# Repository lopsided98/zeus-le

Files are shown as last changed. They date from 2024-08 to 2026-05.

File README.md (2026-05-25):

# zeus-le

### Synchronized wireless audio recording system

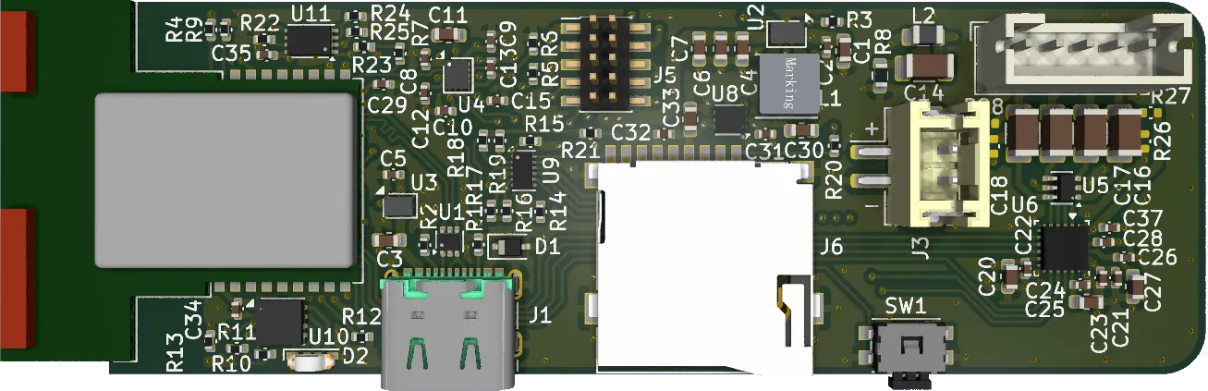
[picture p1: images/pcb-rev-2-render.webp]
Render of zeus-le rev-2 PCB


zeus-le is a system to allow a set of wireless digital audio recorders to maintain sub-sample accurate time synchronization over indefinite periods. A central node broadcasts periodic synchronization packets over Bluetooth LE, which are received by an arbitrary number of recording nodes. The recording nodes use a digital phase-locked loop (PLL) to keep the audio sample clock in sync with the reference. The PLL is implemented using a Kalman filter and linear quadratic regulator.

This repository contains both firmware source code and a custom PCB design for the audio recording hardware. The firmware is written in C for a Nordic nRF53 running Zephyr RTOS. The PCB is designed in KiCad and hosts an nRF53+nRF7002 module, battery charger, SD card, audio ADC and voltage regulators.

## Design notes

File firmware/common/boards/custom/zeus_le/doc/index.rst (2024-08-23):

.. _zeus_le_nrf5340:

zeus-le
###################

Overview
********

zeus-le board is based on the Fanstel WT02C40C module, using the Nordic
Semiconductor nRF5340 ARM Cortex-M33 SoC.

The nRF5340 inside the WT02C40C module is a
dual-core SoC based on the Arm® Cortex®-M33 architecture, with:

* a full-featured Arm Cortex-M33F core with DSP instructions, FPU, and
  Armv8-M Security Extension, running at up to 128 MHz, referred to as
  the **application core**
* a secondary Arm Cortex-M33 core, with a reduced feature set, running
  at a fixed 64 MHz, referred to as the **network core**.

The ``zeus_le/nrf5340/cpuapp`` build target provides support for the application
core on the nRF5340 SoC. The ``zeus_le/nrf5340/cpuapp`` build target provides
support for the network core on the nRF5340 SoC.

nRF5340 SoC provides support for the following devices:

* :abbr:`ADC (Analog to Digital Converter)`
* CLOCK
* FLASH
* :abbr:`GPIO (General Purpose Input Output)`
* :abbr:`IDAU (Implementation Defined Attribution Unit)`
* :abbr:`I2C (Inter-Integrated Circuit)`
* :abbr:`MPU (Memory Protection Unit)`
* :abbr:`NVIC (Nested Vectored Interrupt Controller)`
* :abbr:`PWM (Pulse Width Modulation)`
* :abbr:`QSPI (Quad Serial Peripheral Interface)`
* RADIO (Bluetooth Low Energy and 802.15.4)
* :abbr:`RTC (nRF RTC System Clock)`
* Segger RTT (RTT Console)
* :abbr:`SPI (Serial Peripheral Interface)`
* :abbr:`UARTE (Universal asynchronous receiver-transmitter)`
* :abbr:`WDT (Watchdog Timer)`

zeus-le

     zeus-le

The `pcb` directory contains the board's schematic.

Hardware
********
- Synchronized audio recording board
- Nordic nRF5340 SoC Solution
- A recommnded 3rd-party module by Nordic Semiconductor.
- Dual-core Arm® Cortex® M33
- 1MB/256KB Flash Memory; 512kB/ 64kB RAM
- Supports BT5 Long Range Features
- Bluetooth specification v5.2
- Supports Bluetooth Direction Finding & Mesh
- Supports Bluetooth low energy audio
- Chip Antenna
- Highly flexible multiprotocol SoC ideally suited for Bluetooth® Low Energy, ANT+, Zigbee, Thread (802.15.4) ultra low-power wireless applications.
- RGB LED with animation driver
- Pushbutton
- 1 USB-C connector for battery charging and communication
- BMDU connector for FW programing and UART communication

Supported Features
==================

The ``zeus_le_nrf5340/cpuapp`` board configuration supports the following
hardware features:

+-----------+------------+----------------------+
| Interface | Controller | Driver/Component     |
+===========+============+======================+
| ADC       | on-chip    | adc                  |
+-----------+------------+----------------------+
| CLOCK     | on-chip    | clock_control        |
+-----------+------------+----------------------+
| FLASH     | on-chip    | flash                |
+-----------+------------+----------------------+
| GPIO      | on-chip    | gpio                 |
+-----------+------------+----------------------+
| I2C(M)    | on-chip    | i2c                  |
+-----------+------------+----------------------+
| MPU       | on-chip    | arch/arm             |
+-----------+------------+----------------------+
| NVIC      | on-chip    | arch/arm             |
+-----------+------------+----------------------+
| QSPI(M)   | on-chip    | nor                  |
+-----------+------------+----------------------+
| PWM       | on-chip    | pwm                  |
+-----------+------------+----------------------+
| RTC       | on-chip    | system clock         |
+-----------+------------+----------------------+
| SPI(M/S)  | on-chip    | spi                  |
+-----------+------------+----------------------+
| SPU       | on-chip    | system protection    |
+-----------+------------+----------------------+
| UARTE     | on-chip    | serial               |
+-----------+------------+----------------------+
| WDT       | on-chip    | watchdog             |
+-----------+------------+----------------------+

The ``zeus_le_nrf5340/cpunet`` board configuration supports the following
hardware features:

+-----------+------------+----------------------+
| Interface | Controller | Driver/Component     |
+===========+============+======================+
| CLOCK     | on-chip    | clock_control        |
+-----------+------------+----------------------+
| FLASH     | on-chip    | flash                |
+-----------+------------+----------------------+
| GPIO      | on-chip    | gpio                 |
+-----------+------------+----------------------+
| I2C(M)    | on-chip    | i2c                  |
+-----------+------------+----------------------+
| MPU       | on-chip    | arch/arm             |
+-----------+------------+----------------------+
| NVIC      | on-chip    | arch/arm             |
+-----------+------------+----------------------+
| RADIO     | on-chip    | Bluetooth,           |
|           |            | ieee802154           |
+-----------+------------+----------------------+
| RTC       | on-chip    | system clock         |
+-----------+------------+----------------------+
| SPI(M/S)  | on-chip    | spi                  |
+-----------+------------+----------------------+
| UARTE     | on-chip    | serial               |
+-----------+------------+----------------------+
| WDT       | on-chip    | watchdog             |
+-----------+------------+----------------------+

Other hardware features have not been enabled yet for this board.
See `MDBT53-DB-40 website`_ and `MDBT53-DB-40 Specification`_
for a complete list of zeus-le board hardware features.

Connections and IOs
===================

LED
---

* LED1 (green) = P0.28
* LED2 (red) = P0.30
* LED3 = P0.31
* LED4 = P0.29

Push buttons
------------

* BUTTON1 = SW1 = P0.24
* BUTTON2 = SW2 = P0.08
* BUTTON3 = SW3 = P0.23
* BUTTON4 = SW4 = P0.09

UART
----
* RX = P0.22
* TX = P0.20
* RTS = P0.19
* CTS = P0.21

Security components
===================

- Implementation Defined Attribution Unit (`IDAU`_) on the application core.
  The IDAU is implemented with the System Protection Unit and is used to
  define secure and non-secure memory maps.  By default, all of the memory
  space  (Flash, SRAM, and peripheral address space) is defined to be secure
  accessible only.
- Secure boot.

Programming and Debugging
*************************

nRF5340 application core supports the Armv8-M Security Extension.
Applications built for the ``zeus_le/nrf5340/cpuapp`` board by
default boot in the Secure state.

nRF5340 network core does not support the Armv8-M Security Extension.
nRF5340 IDAU may configure bus accesses by the nRF5340 network core
to have Secure attribute set; the latter allows to build and run
Secure only applications on the nRF5340 SoC.

Applications for the ``zeus_le_nrf5340`` board configuration can be
built, flashed, and debugged in the usual way. See :ref:`build_an_application` and
:ref:`application_run` for more details on building and running.

.. note::
   Flashing and Debugging Zephyr onto the zeus_le_nrf5340 board
   requires an	external J-Link programmer. The programmer is attached to the J1
   or J9 SWD connector.

Flashing
========

Follow the instructions in the :ref:`nordic_segger` page to install
and configure all the necessary software. Further information can be
found in :ref:`nordic_segger_flashing`. Then build and flash
applications as usual (see :ref:`build_an_application` and
:ref:`application_run` for more details).

.. warning::

   The nRF5340 has a flash read-back protection feature. When flash read-back
   protection is active, you will need to recover the chip before reflashing.
   If you are flashing with :ref:`west <west-build-flash-debug>`, run
   this command for more details on the related ``--recover`` option:

Here is an example for the :ref:`hello_world` application.

Use a USB to TTL converter to connect the computer and zeus_le_nrf5340
J10 connector. Then run your favorite terminal program to listen for output.

.. code-block:: console

   $ minicom -D <tty_device> -b 115200

Replace :code:`<tty_device>` with the port where the USB to TTL converter
can be found. For example, under Linux, :code:`/dev/ttyUSB0`.

Then build and flash the application in the usual way.

.. zephyr-app-commands::
   :zephyr-app: samples/hello_world
   :board: zeus_le_nrf5340
   :goals: build flash

Debugging
=========

The ``zeus_le_nrf5340`` board does not have an on-board-J-Link debug IC,
however, instructions from the :ref:`nordic_segger` page also apply to this board.
Use the Debug out connector of nRF52x DK to connect to the J1 connector, and use SEGGER
J-Link OB IF to debug.

Refer to the :ref:`nordic_segger` page to learn about debugging Nordic
boards with a Segger IC.

References
**********

.. _IDAU:
   https://developer.arm.com/docs/100690/latest/attribution-units-sau-and-idau

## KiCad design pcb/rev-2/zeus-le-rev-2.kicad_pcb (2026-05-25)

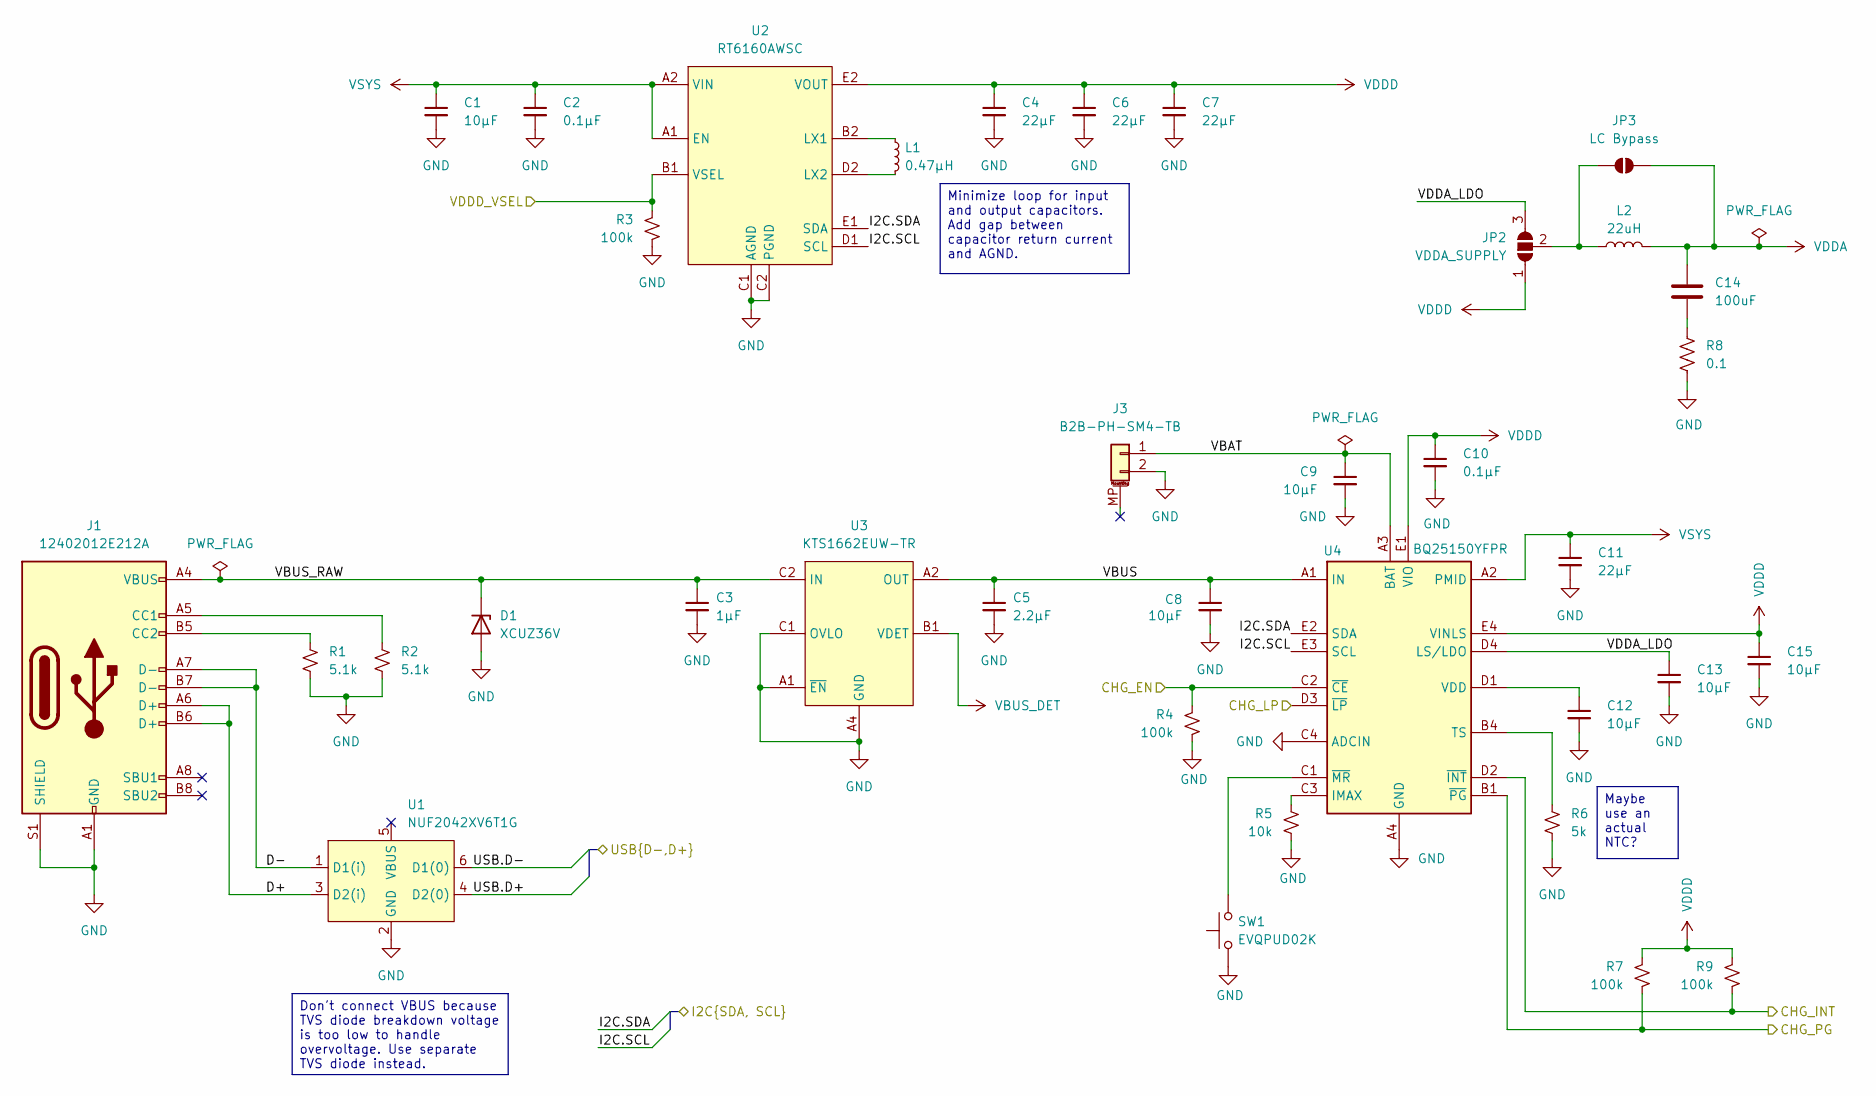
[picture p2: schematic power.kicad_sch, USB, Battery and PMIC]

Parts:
C1: 10µF; C_0603_1608Metric
C2, C10: 0.1µF; C_0402_1005Metric_Silkscreen_Clearance
C3: 1µF; C_0603_1608Metric
C4, C6, C7, C11: 22µF; C_0603_1608Metric
C5: 2.2µF; C_0402_1005Metric_Silkscreen_Clearance
C8, C9, C12, C13, C15: 10µF; C_0402_1005Metric_Silkscreen_Clearance
C14: 100uF; C_1206_3216Metric
D1: XCUZ36V; D_SOD-323
J1: 12402012E212A; USB_C_Receptacle_Amphenol_12402012E21-2A
J3: B2B-PH-SM4-TB; JST_PH_B2B-PH-SM4-TB_1x02-1MP_P2.00mm_Vertical; mouser# 306-B2BPHSM4TBLFSN
JP2: VDDA_SUPPLY; SolderJumper-3_P2.0mm_Open_TrianglePad1.0x1.5mm
JP3: LC Bypass; SolderJumper-2_P1.3mm_Open_TrianglePad1.0x1.5mm
L1: 0.47µH; L_Bourns_SRP4020FA_4.1x4.1mm
L2: 22uH; L_0805_2012Metric
R1, R2: 5.1k; R_0402_1005Metric_Silkscreen_Clearance
R3, R4, R7, R9: 100k; R_0402_1005Metric_Silkscreen_Clearance
R5: 10k; R_0402_1005Metric_Silkscreen_Clearance
R6: 5k; R_0402_1005Metric_Silkscreen_Clearance
R8: 0.1; R_0603_1608Metric
SW1: EVQPUD02K; Panasonic_EVQPUM_EVQPUD
U1: NUF2042XV6T1G; SOT-563
U2: RT6160AWSC; Richtek_WLCSP-15_1.4x2.3mm_Layout3x5_P0.4mm_NSMD
U3: KTS1662EUW-TR; Kinetic_WLCSP-12_1.94x1.28mm_Layout4x3_P0.4mm_Ball0.25mm_Pa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
U4: BQ25150YFPR; Texas_DSBGA-20_1.615x2.015mm_Layout4x5_P0.4mm_NSMD

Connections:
/Audio/I2C.SCL: U2.D1 (SCL), U4.E3 (SCL); also elsewhere on the board
/Audio/I2C.SDA: U2.E1 (SDA), U4.E2 (SDA); also elsewhere on the board
/MCU/CHG_EN: R4.1, U4.C2 (~CE); also elsewhere on the board
/MCU/CHG_INT: R9.2, U4.D2 (~INT); also elsewhere on the board
/MCU/CHG_LP: U4.D3 (~LP); also elsewhere on the board
/MCU/CHG_PG: R7.2, U4.B1 (~PG); also elsewhere on the board
/MCU/USB.D+: U1.4 (D2(0)); also elsewhere on the board
/MCU/USB.D-: U1.6 (D1(0)); also elsewhere on the board
/MCU/VDDD_VSEL: R3.1, U2.B1 (VSEL); also elsewhere on the board
/Power/D+: J1.A6 (D+), J1.B6 (D+), U1.3 (D2(i))
/Power/D-: J1.A7 (D-), J1.B7 (D-), U1.1 (D1(i))
/Power/VBAT: C9.1, J3.1, U4.A3 (BAT), U4.B3 (BAT)
/Power/VBUS: C5.1, C8.1, U3.A2 (OUT), U3.A3 (OUT), U3.B2 (OUT), U4.A1 (IN)
/Power/VBUS_RAW: C3.1, D1.1 (K), J1.A4 (VBUS), J1.A9 (VBUS), J1.B4 (VBUS), J1.B9 (VBUS), U3.B3 (IN), U3.C2 (IN), U3.C3 (IN)
/Power/VDDA_LDO: C13.1, JP2.3 (B), U4.D4 (LS/LDO)
GND: C1.2, C2.2, C3.2, C4.2, C5.2, C6.2, C7.2, C8.2, C9.2, C10.2, C11.2, C12.2, C13.2, C15.2, D1.2 (A), J1.A1 (GND), J1.A12 (GND), J1.B1 (GND), J1.B12 (GND), J1.S1 (SHIELD), J3.2, R1.2, R2.2, R3.2, R4.2, R5.2, R6.2, R8.2, SW1.1, U1.2 (GND), U2.C1 (AGND), U2.C2 (PGND), U2.C3 (PGND), U3.A1 (~EN), U3.A4 (GND), U3.B4 (GND), U3.C1 (OVLO), U3.C4 (GND), U4.A4 (GND), U4.C4 (ADCIN); also elsewhere on the board
unnamed: C14.2, R8.1
unnamed: J1.A5 (CC1), R2.1
unnamed: J1.B5 (CC2), R1.1
unnamed: JP2.2 (C), JP3.1 (A), L2.1
unnamed: L1.1, U2.B2 (LX1), U2.B3 (LX1)
unnamed: L1.2, U2.D2 (LX2), U2.D3 (LX2)
unnamed: R5.1, U4.C3 (IMAX)
unnamed: R6.1, U4.B4 (TS)
unnamed: C12.1, U4.D1 (VDD)
unnamed: SW1.2, U4.C1 (~MR)
VBUS_DET: U3.B1 (VDET); also elsewhere on the board
VDDA: C14.1, JP3.2 (B), L2.2; also elsewhere on the board
VDDD: C4.1, C6.1, C7.1, C10.1, C15.1, JP2.1 (A), R7.1, R9.1, U2.E2 (VOUT), U2.E3 (VOUT), U4.E1 (VIO), U4.E4 (VINLS); also elsewhere on the board
VSYS: C1.1, C2.1, C11.1, U2.A1 (EN), U2.A2 (VIN), U2.A3 (VIN), U4.A2 (PMID), U4.B2 (PMID)

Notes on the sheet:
Minimize loop for input and output capacitors. Add gap between capacitor return current and AGND.
Don't connect VBUS because TVS diode breakdown voltage is too low to handle overvoltage. Use separate TVS diode instead.
Maybe use an actual NTC?

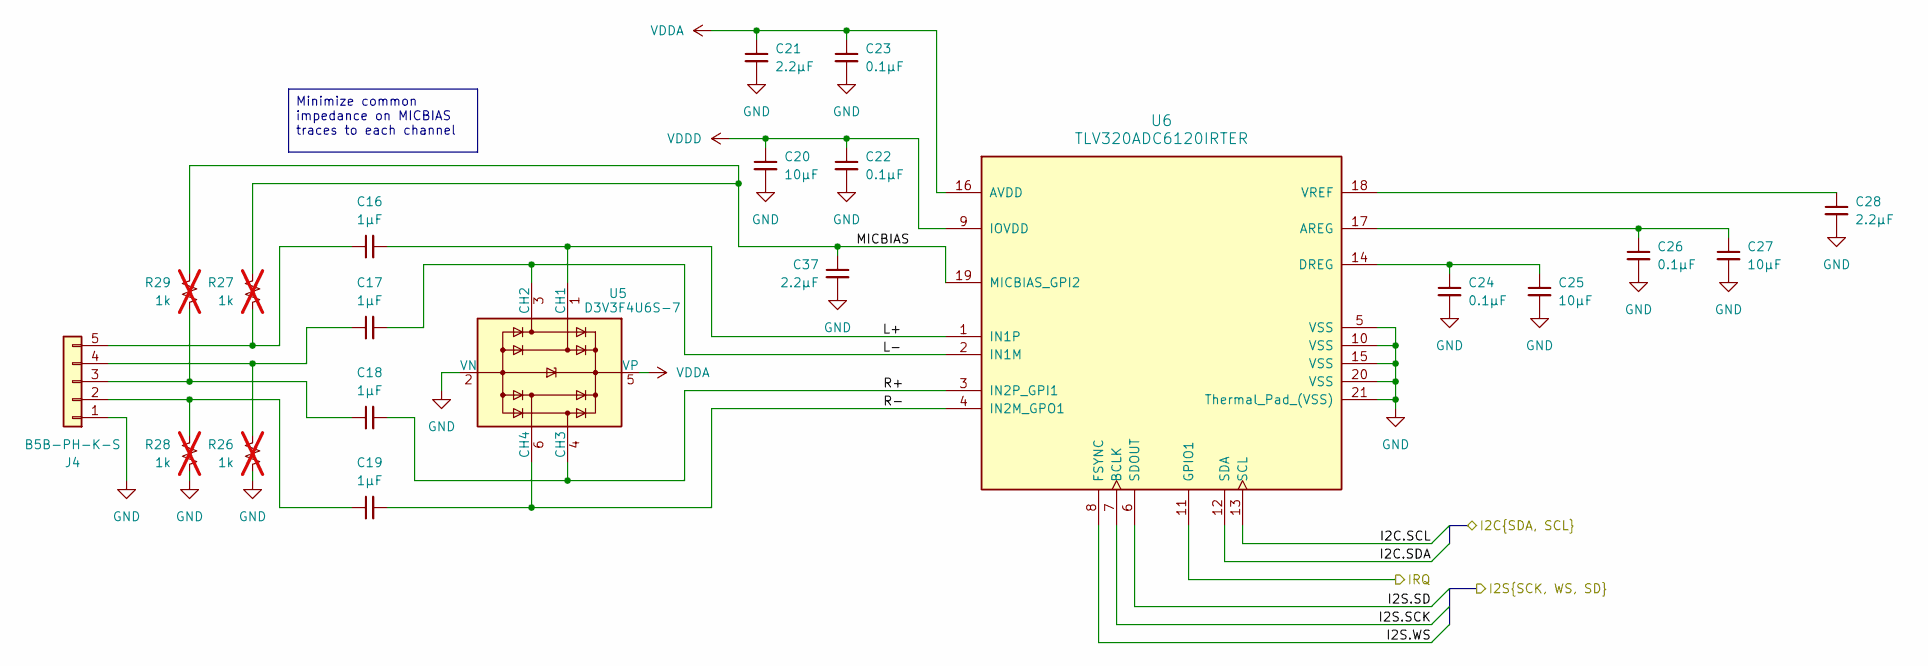
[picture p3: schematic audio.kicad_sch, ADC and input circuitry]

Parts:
C16, C17, C18, C19: 1µF; C_1206_3216Metric
C20, C25, C27: 10µF; C_0603_1608Metric
C21, C28, C37: 2.2µF; C_0402_1005Metric_Silkscreen_Clearance
C22, C23, C24, C26: 0.1µF; C_0402_1005Metric_Silkscreen_Clearance
J4: B5B-PH-K-S; JST_PH_B5B-PH-K_1x05_P2.00mm_Vertical
R26, R27, R28, R29: 1k; R_0402_1005Metric_Silkscreen_Clearance; not fitted
U5: D3V3F4U6S-7; SOT-363_SC-70-6
U6: TLV320ADC6120IRTER; Texas_RTE_WQFN-20-1EP_3x3mm_P0.5mm_EP1.4x1.4mm_ThermalVias

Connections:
/Audio/I2C.SCL: U6.13 (SCL); also elsewhere on the board
/Audio/I2C.SDA: U6.12 (SDA); also elsewhere on the board
/Audio/I2S.SCK: U6.7 (BCLK); also elsewhere on the board
/Audio/I2S.SD: U6.6 (SDOUT); also elsewhere on the board
/Audio/I2S.WS: U6.8 (FSYNC); also elsewhere on the board
/Audio/IRQ: U6.11 (GPIO1); also elsewhere on the board
/Audio/L+: C16.2, U5.1 (CH1), U6.1 (IN1P)
/Audio/L-: C17.2, U5.3 (CH2), U6.2 (IN1M)
/Audio/MICBIAS: C37.1, R27.1, R29.1, U6.19 (MICBIAS_GPI2)
/Audio/R+: C18.2, U5.4 (CH3), U6.3 (IN2P_GPI1)
/Audio/R-: C19.2, U5.6 (CH4), U6.4 (IN2M_GPO1)
GND: C20.2, C21.2, C22.2, C23.2, C24.2, C25.2, C26.2, C27.2, C28.2, C37.2, J4.1, R26.2, R28.2, U5.2 (VN), U6.5 (VSS), U6.10 (VSS), U6.15 (VSS), U6.20 (VSS), U6.21 (Thermal_Pad_(VSS)); also elsewhere on the board
unnamed: C19.1, J4.2, R28.1
unnamed: C18.1, J4.3, R29.2
unnamed: C17.1, J4.4, R26.1
unnamed: C16.1, J4.5, R27.2
unnamed: C26.1, C27.1, U6.17 (AREG)
unnamed: C24.1, C25.1, U6.14 (DREG)
unnamed: C28.1, U6.18 (VREF)
VDDA: C21.1, C23.1, U5.5 (VP), U6.16 (AVDD); also elsewhere on the board
VDDD: C20.1, C22.1, U6.9 (IOVDD); also elsewhere on the board

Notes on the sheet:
Minimize common impedance on MICBIAS traces to each channel

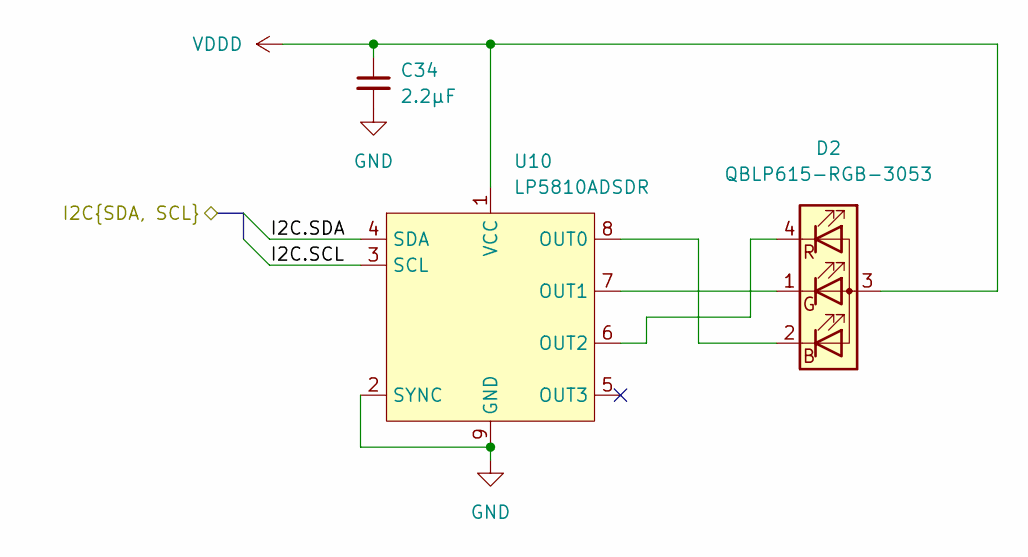
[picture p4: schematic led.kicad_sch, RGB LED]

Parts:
C34: 2.2µF; C_0402_1005Metric_Silkscreen_Clearance
D2: QBLP615-RGB-3053; LED_QBLP615-RGB-3053
U10: LP5810ADSDR; WSON-8-1EP_3x3mm_P0.65mm_EP1.65x2.4mm_ThermalVias

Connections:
/Audio/I2C.SCL: U10.3 (SCL); also elsewhere on the board
/Audio/I2C.SDA: U10.4 (SDA); also elsewhere on the board
GND: C34.2, U10.2 (SYNC), U10.9 (GND); also elsewhere on the board
unnamed: D2.2 (BK), U10.8 (OUT0)
unnamed: D2.1 (GK), U10.7 (OUT1)
unnamed: D2.4 (RK), U10.6 (OUT2)
VDDD: C34.1, D2.3 (A), U10.1 (VCC); also elsewhere on the board

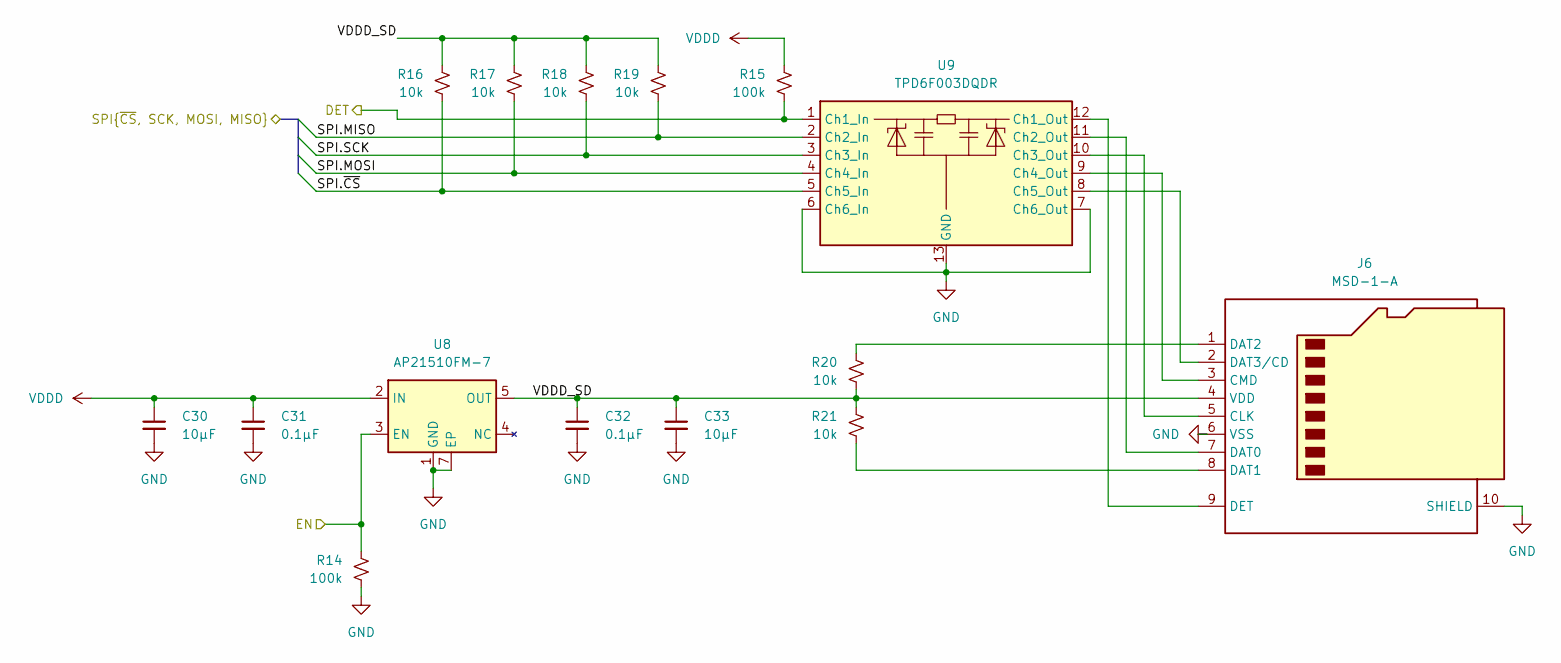
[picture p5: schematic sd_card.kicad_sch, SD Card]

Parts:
C30, C33: 10µF; C_0603_1608Metric
C31, C32: 0.1µF; C_0402_1005Metric_Silkscreen_Clearance
J6: MSD-1-A; microSD_HC_CUI_MSD-1-A
R14, R15: 100k; R_0402_1005Metric_Silkscreen_Clearance
R16, R17, R18, R19, R20, R21: 10k; R_0402_1005Metric_Silkscreen_Clearance
U8: AP21510FM-7; Diodes_UDFN2018-6
U9: TPD6F003DQDR; Texas_R-PWSON-N12_EP0.4x2mm; digikey# 296-25802-1-ND

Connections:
/MCU/SD.MISO: R19.2, U9.2 (Ch2_In); also elsewhere on the board
/MCU/SD.MOSI: R17.2, U9.4 (Ch4_In); also elsewhere on the board
/MCU/SD.SCK: R18.2, U9.3 (Ch3_In); also elsewhere on the board
/MCU/SD.~CS: R16.2, U9.5 (Ch5_In); also elsewhere on the board
/MCU/SD_DET: R15.2, U9.1 (Ch1_In); also elsewhere on the board
/MCU/SD_EN: R14.1, U8.3 (EN); also elsewhere on the board
/SD Card/VDDD_SD: C32.1, C33.1, J6.4 (VDD), R16.1, R17.1, R18.1, R19.1, R20.2, R21.1, U8.5 (OUT), U8.6 (OUT)
GND: C30.2, C31.2, C32.2, C33.2, J6.6 (VSS), J6.10 (SHIELD), R14.2, U8.1 (GND), U8.7 (EP), U9.6 (Ch6_In), U9.7 (Ch6_Out), U9.13 (GND); also elsewhere on the board
unnamed: J6.5 (CLK), U9.10 (Ch3_Out)
unnamed: J6.3 (CMD), U9.9 (Ch4_Out)
unnamed: J6.7 (DAT0), U9.11 (Ch2_Out)
unnamed: J6.8 (DAT1), R21.2
unnamed: J6.1 (DAT2), R20.1
unnamed: J6.2 (DAT3/CD), U9.8 (Ch5_Out)
unnamed: J6.9 (DET), U9.12 (Ch1_Out)
VDDD: C30.1, C31.1, R15.1, U8.2 (IN); also elsewhere on the board

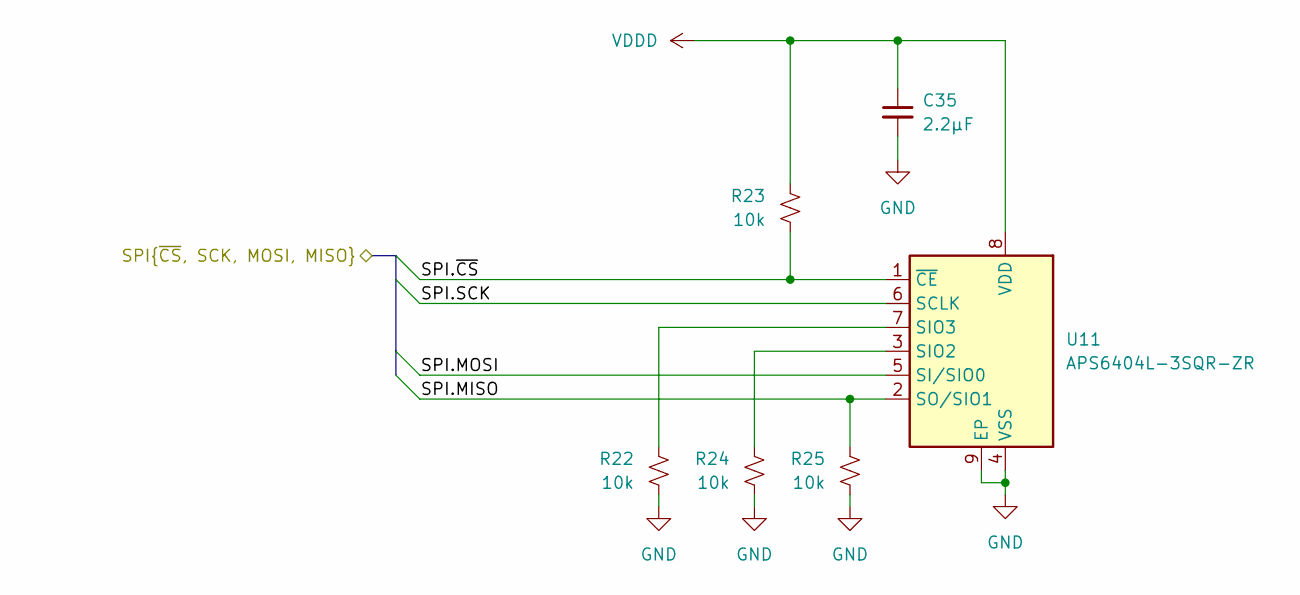
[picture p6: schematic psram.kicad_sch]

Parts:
C35: 2.2µF; C_0402_1005Metric_Silkscreen_Clearance
R22, R23, R24, R25: 10k; R_0402_1005Metric_Silkscreen_Clearance
U11: APS6404L-3SQR-ZR; Winbond_USON-8-1EP_3x2mm_P0.5mm_EP0.2x1.6mm

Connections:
/MCU/RAM.MISO: R25.1, U11.2 (SO/SIO1); also elsewhere on the board
/MCU/RAM.MOSI: U11.5 (SI/SIO0); also elsewhere on the board
/MCU/RAM.SCK: U11.6 (SCLK); also elsewhere on the board
/MCU/RAM.~CS: R23.2, U11.1 (~CE); also elsewhere on the board
GND: C35.2, R22.2, R24.2, R25.2, U11.4 (VSS), U11.9 (EP); also elsewhere on the board
unnamed: R24.1, U11.3 (SIO2)
unnamed: R22.1, U11.7 (SIO3)
VDDD: C35.1, R23.1, U11.8 (VDD); also elsewhere on the board

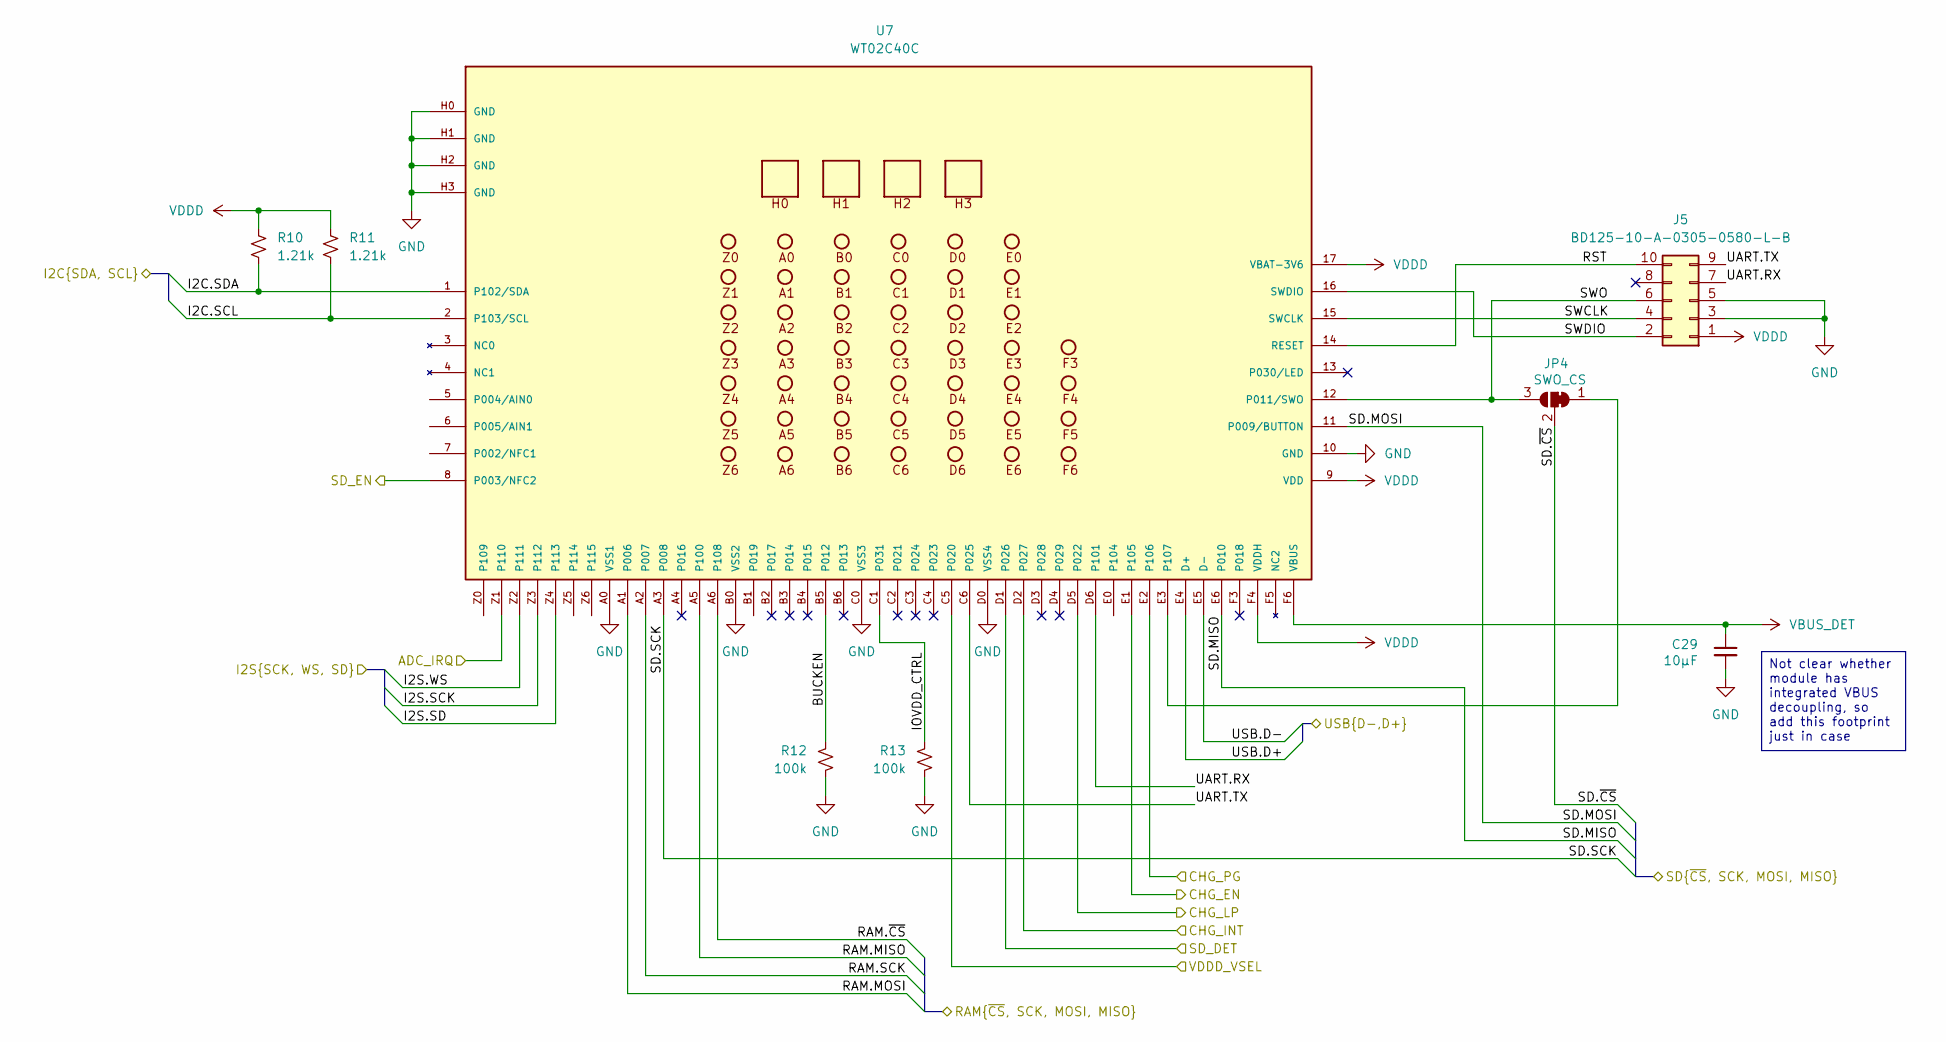
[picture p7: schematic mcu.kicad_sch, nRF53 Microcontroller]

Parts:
C29: 10µF; C_0402_1005Metric_Silkscreen_Clearance
J5: BD125-10-A-0305-0580-L-B; PinHeader_2x05_P1.27mm_Vertical_SMD
JP4: SWO_CS; SolderJumper-3_P2.0mm_Open_TrianglePad1.0x1.5mm
R10, R11: 1.21k; R_0402_1005Metric_Silkscreen_Clearance
R12, R13: 100k; R_0402_1005Metric_Silkscreen_Clearance
U7: WT02C40C; WT02C40C-VC; digikey# 1914-WT02C40CCT-ND

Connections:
/Audio/I2C.SCL: R11.2, U7.2 (P103/SCL); also elsewhere on the board
/Audio/I2C.SDA: R10.2, U7.1 (P102/SDA); also elsewhere on the board
/Audio/I2S.SCK: U7.Z3 (P112); also elsewhere on the board
/Audio/I2S.SD: U7.Z4 (P113); also elsewhere on the board
/Audio/I2S.WS: U7.Z2 (P111); also elsewhere on the board
/Audio/IRQ: U7.Z1 (P110); also elsewhere on the board
/MCU/BUCKEN: R12.1, U7.B5 (P012)
/MCU/CHG_EN: U7.E1 (P105); also elsewhere on the board
/MCU/CHG_INT: U7.D2 (P027); also elsewhere on the board
/MCU/CHG_LP: U7.D5 (P022); also elsewhere on the board
/MCU/CHG_PG: U7.E2 (P106); also elsewhere on the board
/MCU/IOVDD_CTRL: R13.1, U7.C1 (P031)
/MCU/RAM.MISO: U7.A5 (P100); also elsewhere on the board
/MCU/RAM.MOSI: U7.A1 (P006); also elsewhere on the board
/MCU/RAM.SCK: U7.A2 (P007); also elsewhere on the board
/MCU/RAM.~CS: U7.A6 (P108); also elsewhere on the board
/MCU/RST: J5.10, U7.14 (RESET)
/MCU/SD.MISO: U7.E6 (P010); also elsewhere on the board
/MCU/SD.MOSI: U7.11 (P009/BUTTON); also elsewhere on the board
/MCU/SD.SCK: U7.A3 (P008); also elsewhere on the board
/MCU/SD.~CS: JP4.2 (C); also elsewhere on the board
/MCU/SD_DET: U7.D1 (P026); also elsewhere on the board
/MCU/SD_EN: U7.8 (P003/NFC2); also elsewhere on the board
/MCU/SWCLK: J5.4, U7.15 (SWCLK)
/MCU/SWDIO: J5.2, U7.16 (SWDIO)
/MCU/SWO: J5.6, JP4.3 (B), U7.12 (P011/SWO)
/MCU/UART.RX: J5.7, U7.D6 (P101)
/MCU/UART.TX: J5.9, U7.C6 (P025)
/MCU/USB.D+: U7.E4 (D+); also elsewhere on the board
/MCU/USB.D-: U7.E5 (D-); also elsewhere on the board
/MCU/VDDD_VSEL: U7.C5 (P020); also elsewhere on the board
GND: C29.2, J5.3, J5.5, R12.2, R13.2, U7.10 (GND), U7.A0 (VSS1), U7.B0 (VSS2), U7.C0 (VSS3), U7.D0 (VSS4), U7.H0 (GND), U7.H1 (GND), U7.H2 (GND), U7.H3 (GND); also elsewhere on the board
unnamed: JP4.1 (A), U7.E3 (P107)
VBUS_DET: C29.1, U7.F6 (VBUS); also elsewhere on the board
VDDD: J5.1, R10.1, R11.1, U7.9 (VDD), U7.17 (VBAT-3V6), U7.F4 (VDDH); also elsewhere on the board

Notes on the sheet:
Not clear whether module has integrated VBUS decoupling, so add this footprint just in case

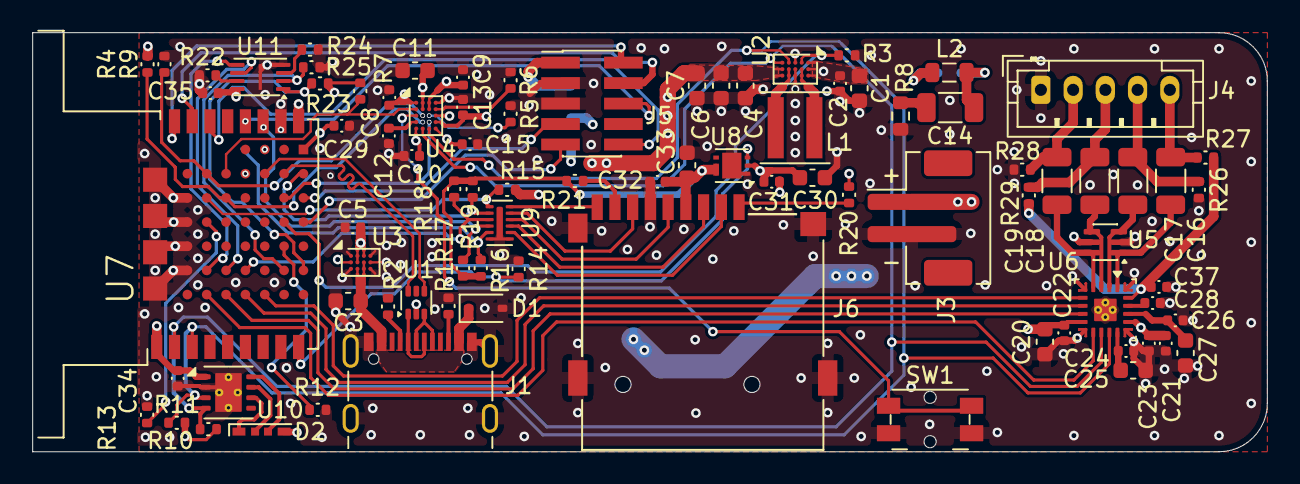
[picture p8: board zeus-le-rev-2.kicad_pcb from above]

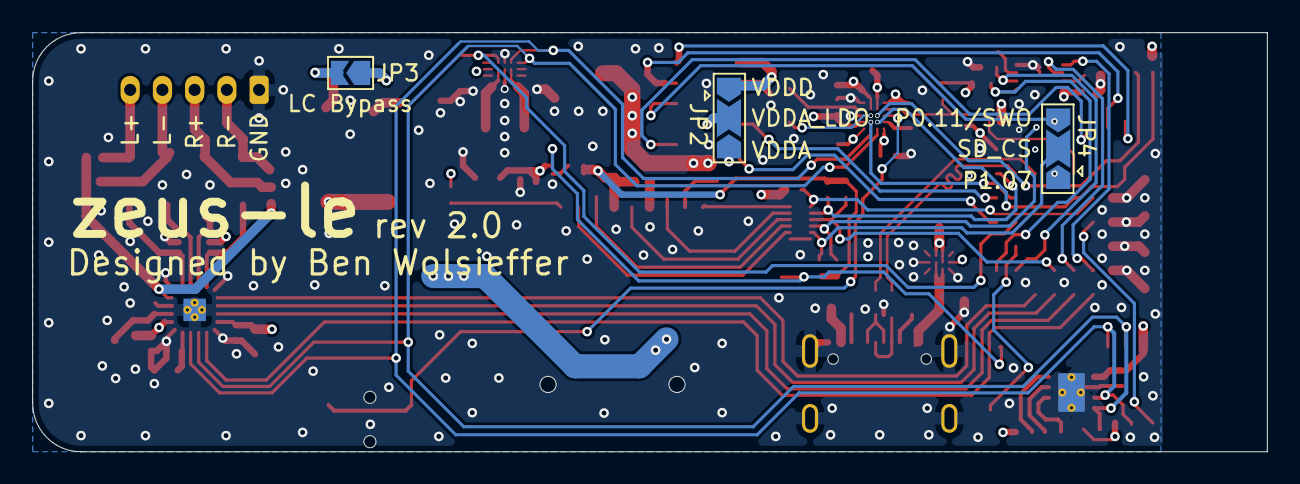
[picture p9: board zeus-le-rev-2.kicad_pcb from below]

Board: 6 copper layers, 76.6 x 26.0 mm, 89 parts (3 on the bottom side), 78 nets.

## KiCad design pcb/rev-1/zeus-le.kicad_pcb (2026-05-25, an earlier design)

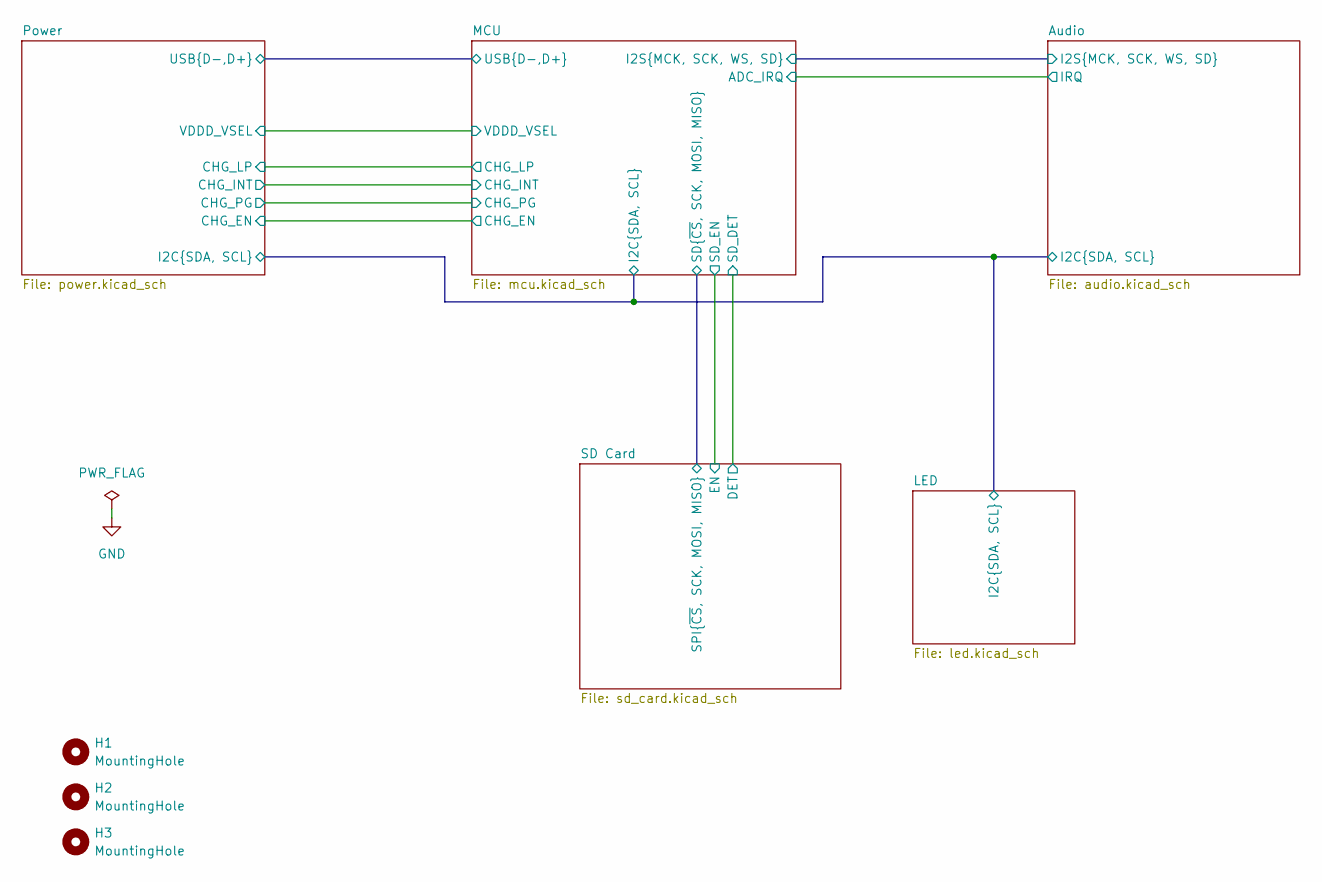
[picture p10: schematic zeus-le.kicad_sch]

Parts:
H1, H2, H3: MountingHole; MountingHole_2.2mm_M2

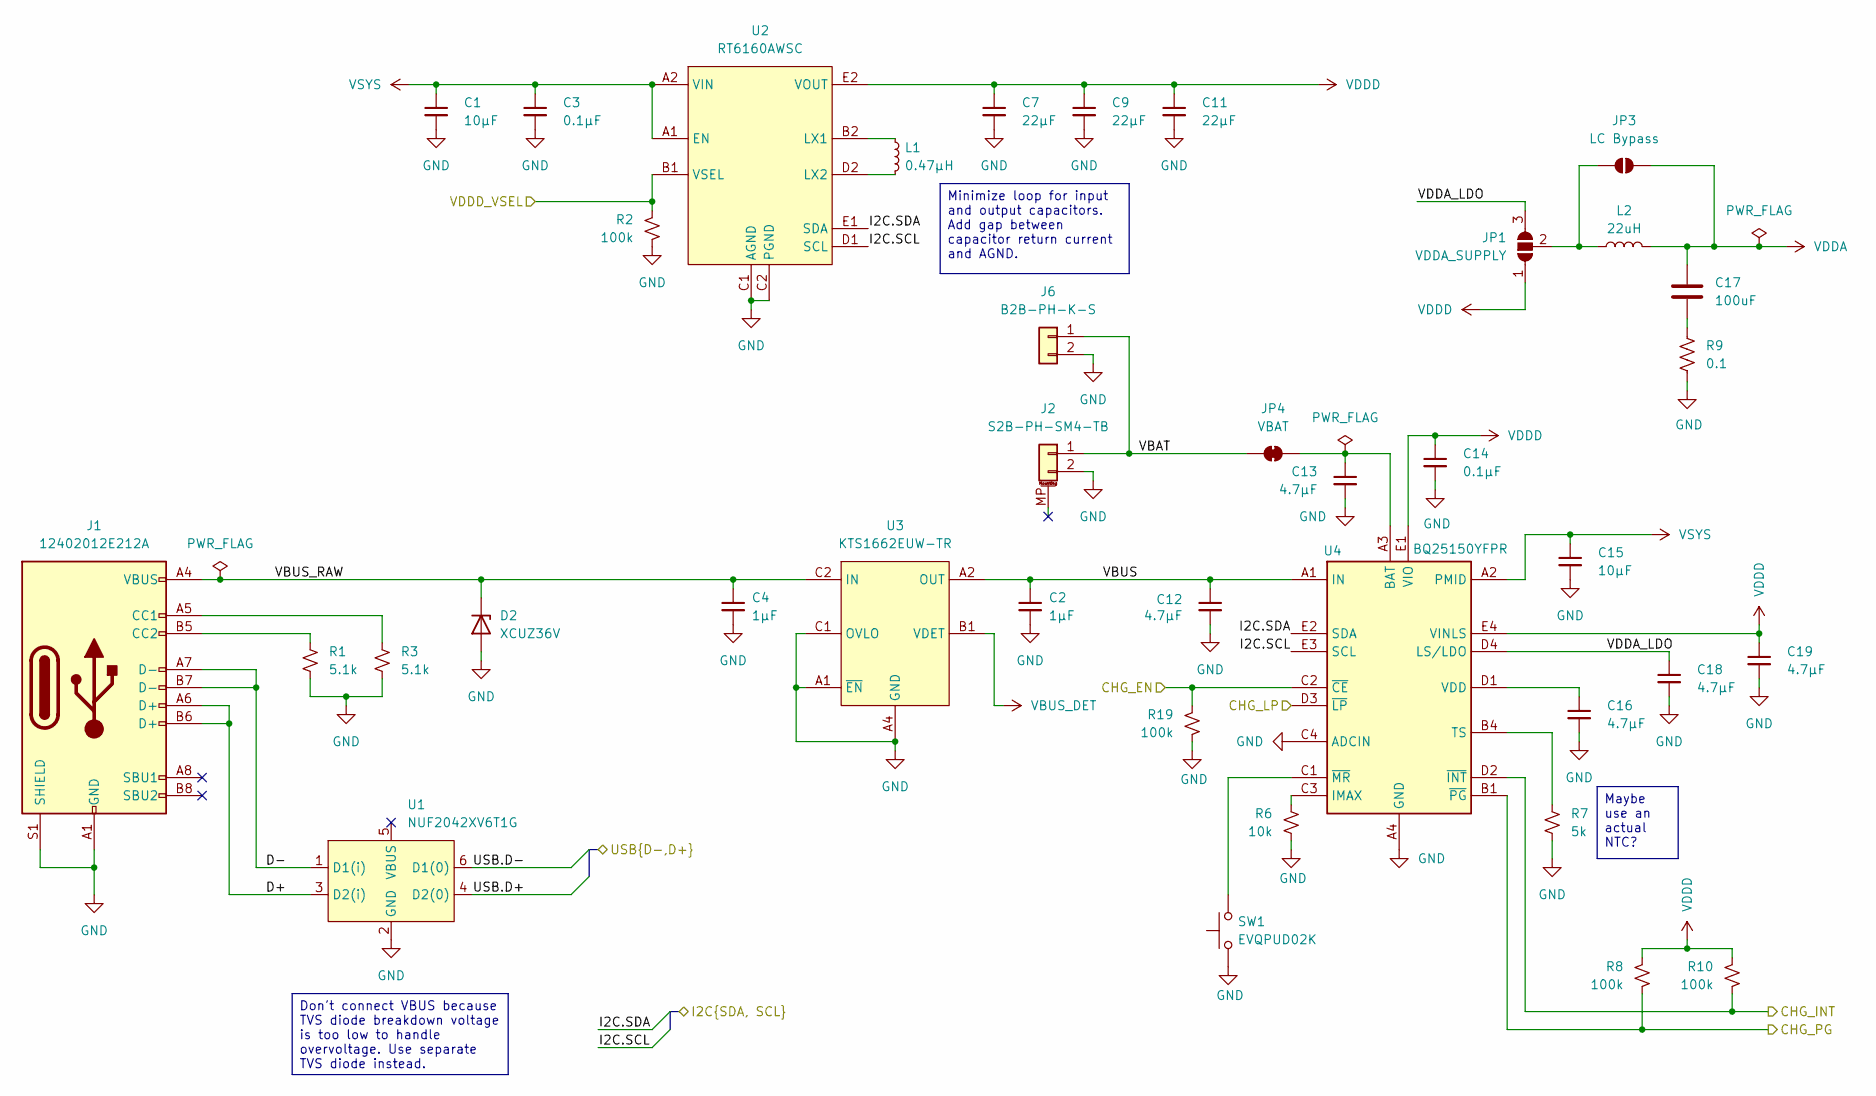
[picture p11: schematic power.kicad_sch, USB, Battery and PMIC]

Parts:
C1, C15: 10µF; C_0603_1608Metric
C2, C4: 1µF; C_0603_1608Metric
C3, C14: 0.1µF; C_0402_1005Metric
C7, C9, C11: 22µF; C_0603_1608Metric
C12, C13, C16, C18, C19: 4.7µF; C_0603_1608Metric
C17: 100uF; C_1206_3216Metric
D2: XCUZ36V; D_SOD-323
J1: 12402012E212A; USB_C_Receptacle_Amphenol_12402012E21-2A
J2: S2B-PH-SM4-TB; JST_PH_S2B-PH-SM4-TB_1x02-1MP_P2.00mm_Horizontal
J6: B2B-PH-K-S; JST_PH_B2B-PH-K_1x02_P2.00mm_Vertical
JP1: VDDA_SUPPLY; SolderJumper-3_P2.0mm_Open_TrianglePad1.0x1.5mm
JP3: LC Bypass; SolderJumper-2_P1.3mm_Open_TrianglePad1.0x1.5mm
JP4: VBAT; SolderJumper-2_P1.3mm_Bridged_RoundedPad1.0x1.5mm
L1: 0.47µH; L_Bourns_SRP4020FA_4.1x4.1mm
L2: 22uH; L_0805_2012Metric
R1, R3: 5.1k; R_0402_1005Metric
R2, R8, R10, R19: 100k; R_0402_1005Metric
R6: 10k; R_0402_1005Metric
R7: 5k; R_0402_1005Metric
R9: 0.1; R_0603_1608Metric
SW1: EVQPUD02K; Panasonic_EVQPUM_EVQPUD
U1: NUF2042XV6T1G; SOT-563
U2: RT6160AWSC; Richtek_WLCSP-15_1.4x2.3mm_Layout3x5_P0.4mm_NSMD
U3: KTS1662EUW-TR; Kinetic_WLCSP-12_1.94x1.28mm_Layout4x3_P0.4mm_Ball0.25mm_Pa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
U4: BQ25150YFPR; Texas_DSBGA-20_1.615x2.015mm_Layout4x5_P0.4mm_NSMD

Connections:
/Audio/I2C.SCL: U2.D1 (SCL), U4.E3 (SCL); also elsewhere on the board
/Audio/I2C.SDA: U2.E1 (SDA), U4.E2 (SDA); also elsewhere on the board
/MCU/CHG_EN: R19.1, U4.C2 (~CE); also elsewhere on the board
/MCU/CHG_INT: R10.2, U4.D2 (~INT); also elsewhere on the board
/MCU/CHG_LP: U4.D3 (~LP); also elsewhere on the board
/MCU/CHG_PG: R8.2, U4.B1 (~PG); also elsewhere on the board
/MCU/USB.D+: U1.4 (D2(0)); also elsewhere on the board
/MCU/USB.D-: U1.6 (D1(0)); also elsewhere on the board
/MCU/VDDD_VSEL: R2.1, U2.B1 (VSEL); also elsewhere on the board
/Power/D+: J1.A6 (D+), J1.B6 (D+), U1.3 (D2(i))
/Power/D-: J1.A7 (D-), J1.B7 (D-), U1.1 (D1(i))
/Power/VBAT: J2.1, J6.1, JP4.1 (A)
/Power/VBUS: C2.1, C12.1, U3.A2 (OUT), U3.A3 (OUT), U3.B2 (OUT), U4.A1 (IN)
/Power/VBUS_RAW: C4.1, D2.1 (K), J1.A4 (VBUS), J1.A9 (VBUS), J1.B4 (VBUS), J1.B9 (VBUS), U3.B3 (IN), U3.C2 (IN), U3.C3 (IN)
/Power/VDDA_LDO: C18.1, JP1.3 (B), U4.D4 (LS/LDO)
GND: C1.2, C2.2, C3.2, C4.2, C7.2, C9.2, C11.2, C12.2, C13.2, C14.2, C15.2, C16.2, C18.2, C19.2, D2.2 (A), J1.A1 (GND), J1.A12 (GND), J1.B1 (GND), J1.B12 (GND), J1.S1 (SHIELD), J2.2, J6.2, R1.2, R2.2, R3.2, R6.2, R7.2, R9.2, R19.2, SW1.1, U1.2 (GND), U2.C1 (AGND), U2.C2 (PGND), U2.C3 (PGND), U3.A1 (~EN), U3.A4 (GND), U3.B4 (GND), U3.C1 (OVLO), U3.C4 (GND), U4.A4 (GND), U4.C4 (ADCIN); also elsewhere on the board
unnamed: C17.2, R9.1
unnamed: J1.A5 (CC1), R3.1
unnamed: J1.B5 (CC2), R1.1
unnamed: JP1.2 (C), JP3.1 (A), L2.1
unnamed: C13.1, JP4.2 (B), U4.A3 (BAT), U4.B3 (BAT)
unnamed: L1.1, U2.B2 (LX1), U2.B3 (LX1)
unnamed: L1.2, U2.D2 (LX2), U2.D3 (LX2)
unnamed: R6.1, U4.C3 (IMAX)
unnamed: R7.1, U4.B4 (TS)
unnamed: C16.1, U4.D1 (VDD)
unnamed: SW1.2, U4.C1 (~MR)
VBUS_DET: U3.B1 (VDET); also elsewhere on the board
VDDA: C17.1, JP3.2 (B), L2.2; also elsewhere on the board
VDDD: C7.1, C9.1, C11.1, C14.1, C19.1, JP1.1 (A), R8.1, R10.1, U2.E2 (VOUT), U2.E3 (VOUT), U4.E1 (VIO), U4.E4 (VINLS); also elsewhere on the board
VSYS: C1.1, C3.1, C15.1, U2.A1 (EN), U2.A2 (VIN), U2.A3 (VIN), U4.A2 (PMID), U4.B2 (PMID)

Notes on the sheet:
Minimize loop for input and output capacitors. Add gap between capacitor return current and AGND.
Don't connect VBUS because TVS diode breakdown voltage is too low to handle overvoltage. Use separate TVS diode instead.
Maybe use an actual NTC?

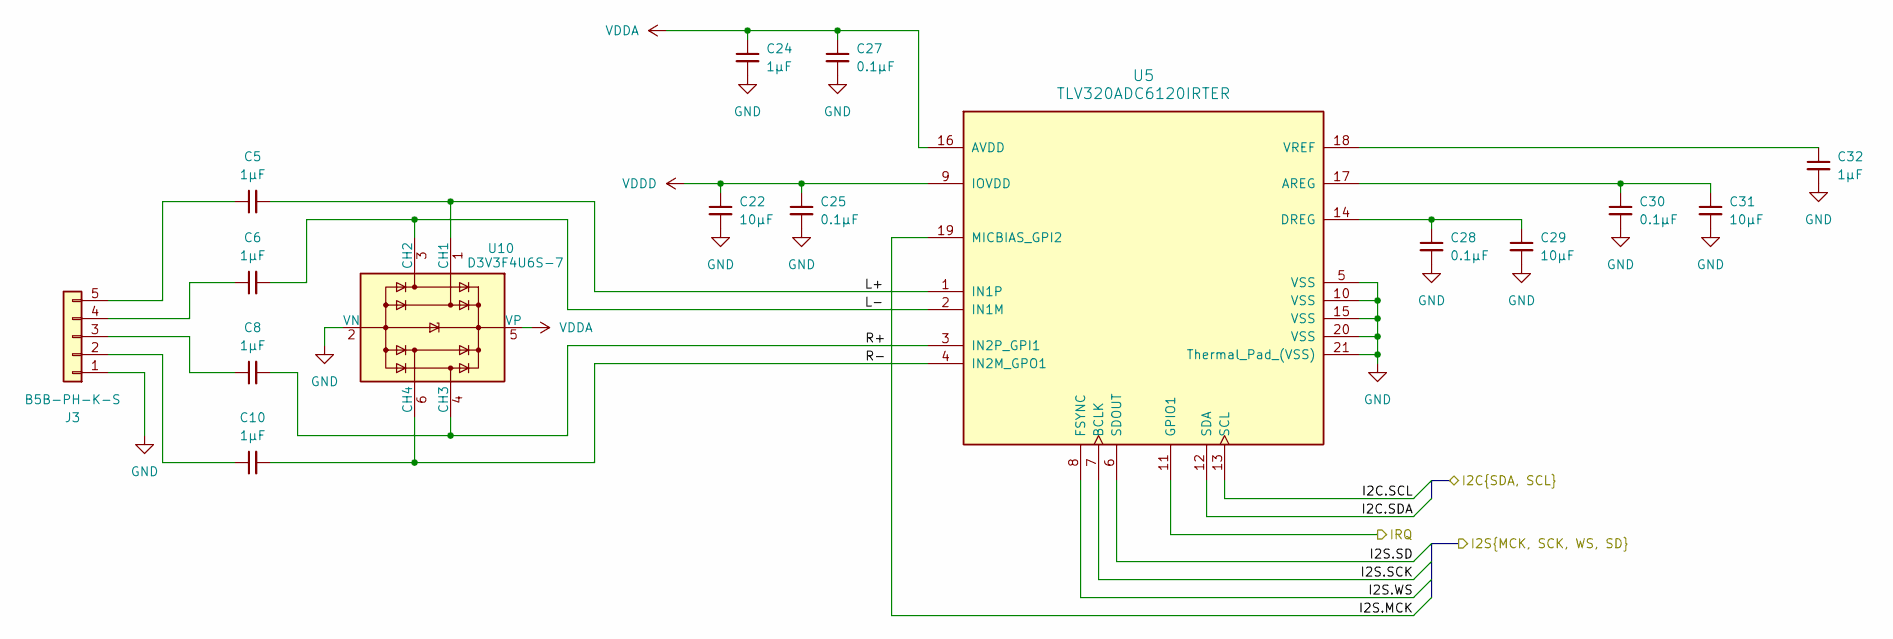
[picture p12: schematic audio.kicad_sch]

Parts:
C5, C6, C8, C10: 1µF; C_1206_3216Metric
C22, C29, C31: 10µF; C_0603_1608Metric
C24, C32: 1µF; C_0603_1608Metric
C25, C27, C28, C30: 0.1µF; C_0402_1005Metric
J3: B5B-PH-K-S; JST_PH_B5B-PH-K_1x05_P2.00mm_Vertical
U5: TLV320ADC6120IRTER; Texas_RTE_WQFN-20-1EP_3x3mm_P0.5mm_EP1.4x1.4mm_ThermalVias
U10: D3V3F4U6S-7; SOT-363_SC-70-6

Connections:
/Audio/I2C.SCL: U5.13 (SCL); also elsewhere on the board
/Audio/I2C.SDA: U5.12 (SDA); also elsewhere on the board
/Audio/I2S.MCK: U5.19 (MICBIAS_GPI2); also elsewhere on the board
/Audio/I2S.SCK: U5.7 (BCLK); also elsewhere on the board
/Audio/I2S.SD: U5.6 (SDOUT); also elsewhere on the board
/Audio/I2S.WS: U5.8 (FSYNC); also elsewhere on the board
/Audio/IRQ: U5.11 (GPIO1); also elsewhere on the board
/Audio/L+: C5.2, U5.1 (IN1P), U10.1 (CH1)
/Audio/L-: C6.2, U5.2 (IN1M), U10.3 (CH2)
/Audio/R+: C8.2, U5.3 (IN2P_GPI1), U10.4 (CH3)
/Audio/R-: C10.2, U5.4 (IN2M_GPO1), U10.6 (CH4)
GND: C22.2, C24.2, C25.2, C27.2, C28.2, C29.2, C30.2, C31.2, C32.2, J3.1, U5.5 (VSS), U5.10 (VSS), U5.15 (VSS), U5.20 (VSS), U5.21 (Thermal_Pad_(VSS)), U10.2 (VN); also elsewhere on the board
unnamed: C10.1, J3.2
unnamed: C8.1, J3.3
unnamed: C6.1, J3.4
unnamed: C5.1, J3.5
unnamed: C30.1, C31.1, U5.17 (AREG)
unnamed: C28.1, C29.1, U5.14 (DREG)
unnamed: C32.1, U5.18 (VREF)
VDDA: C24.1, C27.1, U5.16 (AVDD), U10.5 (VP); also elsewhere on the board
VDDD: C22.1, C25.1, U5.9 (IOVDD); also elsewhere on the board

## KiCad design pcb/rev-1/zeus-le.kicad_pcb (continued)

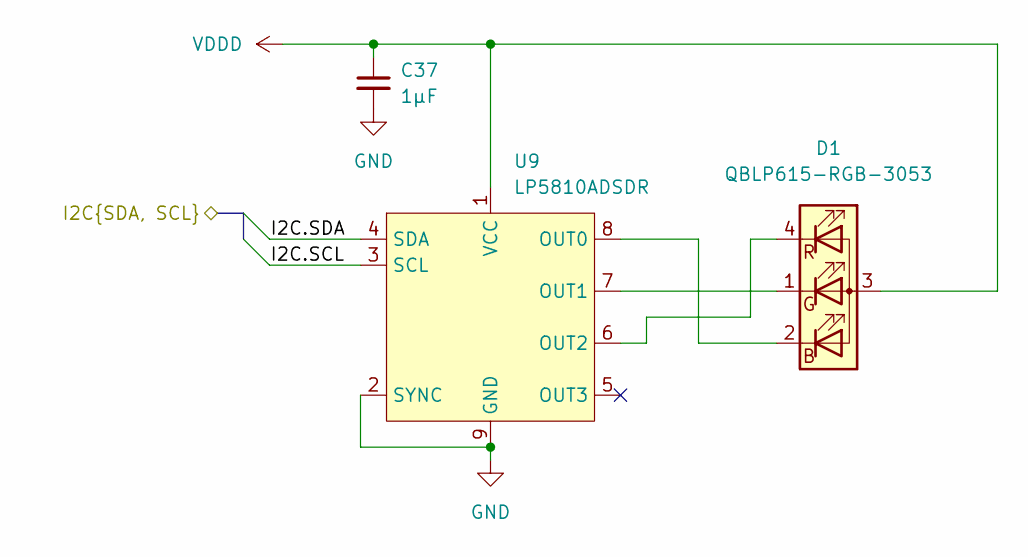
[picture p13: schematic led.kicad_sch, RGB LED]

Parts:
C37: 1µF; C_0603_1608Metric
D1: QBLP615-RGB-3053; LED_QBLP615-RGB-3053
U9: LP5810ADSDR; WSON-8-1EP_3x3mm_P0.65mm_EP1.65x2.4mm_ThermalVias

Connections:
/Audio/I2C.SCL: U9.3 (SCL); also elsewhere on the board
/Audio/I2C.SDA: U9.4 (SDA); also elsewhere on the board
GND: C37.2, U9.2 (SYNC), U9.9 (GND); also elsewhere on the board
unnamed: D1.2 (BK), U9.8 (OUT0)
unnamed: D1.1 (GK), U9.7 (OUT1)
unnamed: D1.4 (RK), U9.6 (OUT2)
VDDD: C37.1, D1.3 (A), U9.1 (VCC); also elsewhere on the board


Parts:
C33, C36: 10µF; C_0603_1608Metric
C34, C35: 0.1µF; C_0402_1005Metric
J5: MSD-1-A; microSD_HC_CUI_MSD-1-A
R4, R5, R14, R15, R17, R18: 10k; R_0402_1005Metric
R13, R16: 100k; R_0402_1005Metric
U7: AP21510FM-7; Diodes_UDFN2018-6
U8: TPD6F003DQDR; Texas_R-PWSON-N12_EP0.4x2mm; digikey# 296-25802-1-ND

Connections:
/MCU/SD.MISO: R4.2, U8.4 (Ch4_In); also elsewhere on the board
/MCU/SD.MOSI: R17.2, U8.2 (Ch2_In); also elsewhere on the board
/MCU/SD.SCK: R5.2, U8.3 (Ch3_In); also elsewhere on the board
/MCU/SD.~CS: R18.2, U8.1 (Ch1_In); also elsewhere on the board
/MCU/SD_DET: R13.2, U8.5 (Ch5_In); also elsewhere on the board
/MCU/SD_EN: R16.1, U7.3 (EN); also elsewhere on the board
/SD Card/VDDD_SD: C35.1, C36.1, J5.4 (VDD), R4.1, R5.1, R14.2, R15.1, R17.1, R18.1, U7.5 (OUT), U7.6 (OUT)
GND: C33.2, C34.2, C35.2, C36.2, J5.6 (VSS), J5.10 (SHIELD), R16.2, U7.1 (GND), U7.7 (EP), U8.6 (Ch6_In), U8.7 (Ch6_Out), U8.13 (GND); also elsewhere on the board
unnamed: J5.5 (CLK), U8.10 (Ch3_Out)
unnamed: J5.3 (CMD), U8.11 (Ch2_Out)
unnamed: J5.7 (DAT0), U8.9 (Ch4_Out)
unnamed: J5.8 (DAT1), R15.2
unnamed: J5.1 (DAT2), R14.1
unnamed: J5.2 (DAT3/CD), U8.12 (Ch1_Out)
unnamed: J5.9 (DET), U8.8 (Ch5_Out)
VDDD: C33.1, C34.1, R13.1, U7.2 (IN); also elsewhere on the board


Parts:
C20: 4.7µF; C_0603_1608Metric
J4: BD125-10-A-0305-0580-L-B; PinHeader_2x05_P1.27mm_Vertical_SMD
JP2: SWO_CS; SolderJumper-3_P2.0mm_Open_TrianglePad1.0x1.5mm
R11, R12: 1.21k; R_0402_1005Metric
R20, R21: 100k; R_0402_1005Metric
U6: WT02C40C-VC

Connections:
/Audio/I2C.SCL: R12.2, U6.2 (P103/SCL); also elsewhere on the board
/Audio/I2C.SDA: R11.2, U6.1 (P102/SDA); also elsewhere on the board
/Audio/I2S.MCK: U6.Z0 (P109); also elsewhere on the board
/Audio/I2S.SCK: U6.Z1 (P110); also elsewhere on the board
/Audio/I2S.SD: U6.Z3 (P112); also elsewhere on the board
/Audio/I2S.WS: U6.Z2 (P111); also elsewhere on the board
/Audio/IRQ: U6.Z4 (P113); also elsewhere on the board
/MCU/CHG_EN: U6.A6 (P108); also elsewhere on the board
/MCU/CHG_INT: U6.A5 (P100); also elsewhere on the board
/MCU/CHG_LP: U6.Z6 (P115); also elsewhere on the board
/MCU/CHG_PG: U6.Z5 (P114); also elsewhere on the board
/MCU/RST: J4.10, U6.14 (RESET)
/MCU/SD.MISO: U6.E6 (P010); also elsewhere on the board
/MCU/SD.MOSI: U6.11 (P009/BUTTON); also elsewhere on the board
/MCU/SD.SCK: U6.A3 (P008); also elsewhere on the board
/MCU/SD.~CS: JP2.2 (C); also elsewhere on the board
/MCU/SD_DET: U6.A1 (P006); also elsewhere on the board
/MCU/SD_EN: U6.8 (P003/NFC2); also elsewhere on the board
/MCU/SWCLK: J4.4, U6.15 (SWCLK)
/MCU/SWDIO: J4.2, U6.16 (SWDIO)
/MCU/SWO: J4.6, JP2.3 (B), U6.12 (P011/SWO)
/MCU/UART.RX: J4.7, U6.D6 (P101)
/MCU/UART.TX: J4.9, U6.C6 (P025)
/MCU/USB.D+: U6.E4 (D+); also elsewhere on the board
/MCU/USB.D-: U6.E5 (D-); also elsewhere on the board
/MCU/VDDD_VSEL: U6.C5 (P020); also elsewhere on the board
GND: C20.2, J4.3, J4.5, R20.2, R21.2, U6.10 (GND), U6.A0 (VSS1), U6.B0 (VSS2), U6.C0 (VSS3), U6.D0 (VSS4), U6.H0 (GND), U6.H1 (GND), U6.H2 (GND), U6.H3 (GND); also elsewhere on the board
unnamed: JP2.1 (A), U6.E3 (P107)
unnamed: R20.1, U6.B5 (P012)
unnamed: R21.1, U6.C1 (P031)
VBUS_DET: C20.1, U6.F6 (VBUS); also elsewhere on the board
VDDD: J4.1, R11.1, R12.1, U6.9 (VDD), U6.17 (VBAT-3V6), U6.F4 (VDDH); also elsewhere on the board

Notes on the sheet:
Not clear whether module has integrated VBUS decoupling, so add this footprint just in case



Board: 6 copper layers, 50.0 x 50.0 mm, 83 parts (4 on the bottom side), 73 nets.

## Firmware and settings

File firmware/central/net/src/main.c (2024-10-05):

// SPDX-License-Identifier: GPL-3.0-or-later
#include <nrfx_egu.h>
#include <nrfx_timer.h>
#include <zephyr/drivers/clock_control/nrf_clock_control.h>
#include <zephyr/ipc/ipc_service.h>
#include <zephyr/kernel.h>
#include <zephyr/logging/log.h>

#include "hci_ipc.h"
#include "zeus/protocol.h"
#include "zeus/sync.h"

// Zephyr internal headers, order is important
// clang-format off
#include <bluetooth/controller/ll_sw/pdu_df.h>
#include <bluetooth/controller/ll_sw/nordic/lll/pdu_vendor.h>
#include <bluetooth/controller/ll_sw/pdu.h>
// clang-format on

LOG_MODULE_REGISTER(central_net);

#define PACKET_TIMER_EGU_IDX 0
#define PACKET_TIMER_IDX 2

struct packet_timer {
    uint8_t seq;
    nrfx_timer_t timer;
    struct ipc_ept ept;
    struct onoff_client hf_cli;
} packet_timer;

static const struct ipc_ept_cfg packet_timer_ept_cfg = {
    .name = "packet_timer",
};

static void packet_timer_isr(uint8_t event_idx, void* context) {
    struct packet_timer* t = (struct packet_timer*)context;

    const struct pdu_adv* pdu = (const struct pdu_adv*)NRF_RADIO->PACKETPTR;
    if (!pdu) {
        LOG_WRN("Null PDU");
        return;
    }
    // Check PDU type, but this is not enough because all extended advertising
    // packets share the same type
    if (pdu->type != PDU_ADV_TYPE_AUX_SYNC_IND) return;
    // Make sure there is no extended advertising header. All extended
    // advertising packets except the periodic packet have a header.
    if (pdu->adv_ext_ind.ext_hdr_len != 0) return;

    const struct zeus_sync_msg msg = {
        .seq = t->seq++,
        .time = nrfx_timer_capture_get(&t->timer, NRF_TIMER_CC_CHANNEL0),
    };

    ipc_service_send(&t->ept, &msg, sizeof(msg));
}

static int packet_timer_init(void) {
    int err;
    nrfx_err_t nerr;
    const struct device* ipc = DEVICE_DT_GET(DT_NODELABEL(ipc0));

    err = ipc_service_open_instance(ipc);
    if (err < 0 && err != -EALREADY) {
        LOG_ERR("failed to initialize IPC (err %d)\n", err);
        return err;
    }
    err = ipc_service_register_endpoint(ipc, &packet_timer.ept,
                                        &packet_timer_ept_cfg);
    if (err < 0) {
        LOG_ERR("failed to register IPC endpoint (err %d)\n", err);
        return err;
    }

    packet_timer.timer = (nrfx_timer_t)NRFX_TIMER_INSTANCE(PACKET_TIMER_IDX);

    // Setup 32-bit 16 MHz timer to capture on radio end event
    nerr = nrfx_timer_init(&packet_timer.timer,
                           &(nrfx_timer_config_t){
                               .frequency = ZEUS_TIME_NOMINAL_FREQ,
                               .mode = NRF_TIMER_MODE_TIMER,
                               .bit_width = NRF_TIMER_BIT_WIDTH_32,
                           },
                           NULL);
    NRFX_ASSERT(NRFX_SUCCESS == nerr);

    // Subscribe to radio end event through existing DPPI channel configured by
    // BLE driver
    nrf_timer_subscribe_set(packet_timer.timer.p_reg, NRF_TIMER_TASK_CAPTURE0,
                            HAL_SW_SWITCH_TIMER_CLEAR_PPI);

    nrfx_egu_t egu = NRFX_EGU_INSTANCE(PACKET_TIMER_EGU_IDX);

    nrfx_egu_init(&egu, NRFX_EGU_DEFAULT_CONFIG_IRQ_PRIORITY, packet_timer_isr,
                  &packet_timer);
    IRQ_CONNECT(NRFX_IRQ_NUMBER_GET(NRF_EGU_INST_GET(PACKET_TIMER_EGU_IDX)), 5,
                NRFX_EGU_INST_HANDLER_GET(PACKET_TIMER_EGU_IDX), 0, 0);

    // Use EGU to fire interrupt when packet is transmitted
    nrf_egu_subscribe_set(egu.p_reg, NRF_EGU_TASK_TRIGGER0,
                          HAL_SW_SWITCH_TIMER_CLEAR_PPI);
    nrfx_egu_int_enable(&egu, NRF_EGU_INT_TRIGGERED0);

    // Keep HFCLK enabled and using HFXO all the time. This is required because
    // we need an accurate clock to run the timer.
    struct onoff_manager* mgr =
        z_nrf_clock_control_get_onoff(CLOCK_CONTROL_NRF_SUBSYS_HF);
    sys_notify_init_spinwait(&packet_timer.hf_cli.notify);
    onoff_request(mgr, &packet_timer.hf_cli);

    // Start the timer
    nrfx_timer_enable(&packet_timer.timer);

    return 0;
}

int main(void) {
    int err;

    err = packet_timer_init();
    if (err) {
        return err;
    }

    err = hci_ipc_init();
    if (err) {
        return err;
    }

    LOG_INF("Booted");

    return 0;
}

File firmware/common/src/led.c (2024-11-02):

#include "zeus/led.h"

#include <zephyr/kernel.h>
#include <zephyr/logging/log.h>
#include <zeus/drivers/led/lp58xx.h>

#include "zeus/protocol.h"
#include "zeus/util.h"

LOG_MODULE_REGISTER(led);

/// Interval between LED sync pulses while recording, in sync timer units. Power
/// of two to avoid dealing with uneven interval at timer wraparound.
#define LED_RECORD_SYNC_INTERVAL NHPOT(ZEUS_TIME_NOMINAL_FREQ * 8)

#define LED_CHANNELS 3
#define LED_BLUE 0
#define LED_GREEN 1
#define LED_RED 2

#define LED_FADE_MS 360

#define LED_AEU_FADE(start_pwm, end_pwm)                  \
    (struct lp58xx_aeu_config) {                          \
        .pwm = {start_pwm, end_pwm, 0, 0, 0},             \
        .time_msec = {LED_FADE_MS, 0, 0, 0}, .repeat = 0, \
    }

#define LED_AEU_CONSTANT(pwm_val)                             \
    (struct lp58xx_aeu_config) {                              \
        .pwm = {pwm_val, pwm_val, pwm_val, pwm_val, pwm_val}, \
        .time_msec = {8050, 8050, 8050, 8050},                \
        .repeat = LP58XX_AEU_REPEAT_INFINITE,                 \
    }

static inline struct lp58xx_aeu_config led_aeu_scale(
    struct lp58xx_aeu_config aeu, uint8_t scale_pwm) {
    return (struct lp58xx_aeu_config){
        .pwm =
            {
                aeu.pwm[0] * scale_pwm / 255,
                aeu.pwm[1] * scale_pwm / 255,
                aeu.pwm[2] * scale_pwm / 255,
                aeu.pwm[3] * scale_pwm / 255,
                aeu.pwm[4] * scale_pwm / 255,
            },
        .time_msec =
            {
                aeu.time_msec[0],
                aeu.time_msec[1],
                aeu.time_msec[2],
                aeu.time_msec[3],
            },
        .repeat = aeu.repeat,
    };
}

static inline struct lp58xx_ae_config led_ae_scale(struct lp58xx_ae_config ae,
                                                   uint8_t scale_pwm) {
    return (struct lp58xx_ae_config){
        .pause_start_msec = ae.pause_start_msec,
        .pause_end_msec = ae.pause_end_msec,
        .num_aeu = ae.num_aeu,
        .repeat = ae.repeat,
        .aeu =
            {
                led_aeu_scale(ae.aeu[0], scale_pwm),
                led_aeu_scale(ae.aeu[1], scale_pwm),
                led_aeu_scale(ae.aeu[1], scale_pwm),
            },
    };
}

enum led_power_state {
    /// Not known yet whether the system will boot or power off
    LED_POWER_UNKNOWN,
    LED_POWER_ON,
    LED_POWER_OFF,
};

enum led_record_state {
    LED_RECORD_WAITING,
    LED_RECORD_RUNNING,
    LED_RECORD_IDLE,
};

enum led_battery_state {
    LED_BATTERY_DISCHARGING,
    LED_BATTERY_CHARGING,
    LED_BATTERY_FULL,
    LED_BATTERY_ERROR,
};

enum led_pattern {
    LED_PATTERN_OFF,
    LED_PATTERN_STARTUP,
    LED_PATTERN_BATTERY_CHARGING,
    LED_PATTERN_BATTERY_FULL,
#if IS_ENABLED(CONFIG_ZEUS_NODE_AUDIO)
    LED_PATTERN_IDLE_SYNCED,
    LED_PATTERN_IDLE_NOT_SYNCED,
#elif IS_ENABLED(CONFIG_ZEUS_NODE_CENTRAL)
    LED_PATTERN_IDLE,
#endif
    LED_PATTERN_RECORD_WAITING,
    LED_PATTERN_RECORD_RUNNING,
    LED_PATTERN_COUNT,
};

typedef int(led_pattern_func)(void);

static int led_pattern_off(void);
static int led_pattern_startup(void);
static int led_pattern_battery_charging(void);
static int led_pattern_battery_full(void);
#if IS_ENABLED(CONFIG_ZEUS_NODE_AUDIO)
static int led_pattern_idle_synced(void);
static int led_pattern_idle_not_synced(void);
#elif IS_ENABLED(CONFIG_ZEUS_NODE_CENTRAL)
static int led_pattern_idle(void);
#endif
static int led_pattern_record_waiting(void);
static int led_pattern_record_running(void);

static void led_record_sync_work_handler(struct k_work* work);
static K_WORK_DELAYABLE_DEFINE(led_record_sync_work,
                               led_record_sync_work_handler);

static K_MUTEX_DEFINE(led_mutex);

static const struct led_config {
    const struct device* led;
    struct k_mutex* mutex;
    struct k_work_delayable* record_sync_work;
    led_pattern_func* patterns[LED_PATTERN_COUNT];
} led_config = {
    .led = DEVICE_DT_GET(DT_NODELABEL(rgb_led)),
    .mutex = &led_mutex,
    .record_sync_work = &led_record_sync_work,
    .patterns =
        {
            [LED_PATTERN_OFF] = led_pattern_off,
            [LED_PATTERN_STARTUP] = led_pattern_startup,
            [LED_PATTERN_BATTERY_CHARGING] = led_pattern_battery_charging,
            [LED_PATTERN_BATTERY_FULL] = led_pattern_battery_full,
#if IS_ENABLED(CONFIG_ZEUS_NODE_AUDIO)
            [LED_PATTERN_IDLE_SYNCED] = led_pattern_idle_synced,
            [LED_PATTERN_IDLE_NOT_SYNCED] = led_pattern_idle_not_synced,
#elif IS_ENABLED(CONFIG_ZEUS_NODE_CENTRAL)
            [LED_PATTERN_IDLE] = led_pattern_idle,
#endif
            [LED_PATTERN_RECORD_WAITING] = led_pattern_record_waiting,
            [LED_PATTERN_RECORD_RUNNING] = led_pattern_record_running,
        },
};

static struct led_data {
    enum led_power_state power_state;
    enum led_battery_state battery_state;
#if IS_ENABLED(CONFIG_ZEUS_NODE_AUDIO)
    bool synced;
#endif
    enum led_record_state record_state;
    enum led_pattern pattern;
} led_data = {
    .power_state = LED_POWER_UNKNOWN,
    .battery_state = LED_BATTERY_DISCHARGING,
#if IS_ENABLED(CONFIG_ZEUS_NODE_AUDIO)
    .synced = false,
#endif
    .record_state = LED_RECORD_IDLE,
    .pattern = LED_PATTERN_OFF,
};

static int led_configure_fade_out(uint8_t channel, uint8_t start_pwm) {
    const struct led_config* cfg = &led_config;

    const struct lp58xx_ae_config ae_cfg = {
        .pause_start_msec = 0,
        .pause_end_msec = 0,
        .num_aeu = 1,
        .repeat = 0,
        .aeu = {LED_AEU_FADE(start_pwm, 0)},
    };

    return lp58xx_ae_configure(cfg->led, channel, &ae_cfg);
}

static int led_pattern_off(void) {
    const struct led_config* cfg = &led_config;
    int ret;

    ret = lp58xx_pause(cfg->led);
    if (ret < 0) return ret;

    uint8_t start_pwm[LED_CHANNELS];
    ret = lp58xx_get_auto_pwm(cfg->led, 0, ARRAY_SIZE(start_pwm), start_pwm);
    if (ret < 0) return ret;

    ret = led_configure_fade_out(LED_BLUE, start_pwm[LED_BLUE]);
    if (ret < 0) return ret;

    ret = led_configure_fade_out(LED_GREEN, start_pwm[LED_GREEN]);
    if (ret < 0) return ret;

    ret = led_configure_fade_out(LED_RED, start_pwm[LED_RED]);
    if (ret < 0) return ret;

    return lp58xx_start(cfg->led);
}
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

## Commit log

2023-12-29 WIP packet timing prototype.
2023-12-30 Split out board specific config.
2023-12-30 Add BabbleSim support.
    It doesn't quite work because the simulated EGU is only a stub, but it
    builds.
    [main.c]
2024-01-01 Fix timestamping of packets.
    [main.c]
2024-01-24 Add audio board with timer frequency estimation.
2024-02-11 Add SGTL5000 driver
    Not yet fully tested. Only basic I2C functionality has been tested, not
    actual audio.
2024-02-14 Incomplete USB audio support
    I decided this was too much work for a debugging feature, so it will be
    removed.
    [main.c]
2024-02-23 Send audio over network and add SD card
    Send raw audio data over UDP through the USB network interface.
    Additionally, add support for the SPI SD card.
2024-04-28 Try to sync ADC sampling times
    Don't just keep sampling from drifting over time, try to eliminate any
    initial ADC sampling phase offset between different devices.
2024-04-28 audio: fix WAV bytes per frame
2024-06-21 Initial version of the PCB
    This is pretty much done, except for designing the analog supply filter
    and replacing the USB PD/BC1.2 negotiation chip that cannot actually be
    purchased.
    [audio.kicad_sch, led.kicad_sch, mcu.kicad_sch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]
2024-06-21 pcb: fix LED 3D model file name
    [zeus-le.kicad_pcb]
2024-06-30 pcb: simplify power supply and define LC filter
    [audio.kicad_sch, led.kicad_sch, mcu.kicad_sch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]
2024-07-06 pcb: pretty much the final version
    [audio.kicad_sch, led.kicad_sch, mcu.kicad_sch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]
2024-07-07 pcb: use debug connector with shroud
    This also gets the connector up higher so the cable won't hit the USB
    connector as much.
    [mcu.kicad_sch, zeus-le.kicad_pcb]
2024-07-07 pcb: rotate debug connector
    This prevents it from interfering with the USB connector.
    [mcu.kicad_sch, power.kicad_sch, zeus-le.kicad_pcb]
2024-07-07 pcb: update fills
    [zeus-le.kicad_pcb]
2024-07-20 pcb: rev 1.0 version submitted for manufacturing
    [audio.kicad_sch, mcu.kicad_sch, power.kicad_sch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]
2024-07-20 pcb: fix debug connector part number
    [mcu.kicad_sch, zeus-le.kicad_pcb]
2024-08-01 pcb: remove stray trace
    [zeus-le.kicad_pcb]
2024-08-19 pcb: replace inductor
    Replace power supply inductor with a more readily available and cheaper
    part.
    [power.kicad_sch, zeus-le.kicad_pcb]
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2024-08-23 Temporarily disable audio to allow bringing up board without I2C
2024-08-23 actions: print full build log
    'nix build' has the stupid default of only showing the last few (usually
    irrelevant) lines.
2024-08-24 Fix central build on custom PCB
2024-09-06 Add drivers for battery charger, LED and ADC
    Some of this is still WIP. Also, add an experimental caching layer to
    try to improve filesystem performance (doesn't help much, at least not
    with seeking).
    [charger_bq2515x.c, lp58xx.c, main.c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]
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2024-09-07 bq2515x: mask unused interrupts, disable watchdog
    The BQ2515X has a 50 second watchdog that resets all the charger
    parameters. This was causing the input current limit to be reset, which
    in turn caused the nRF7002 to brown out and stop working.
    [charger_bq2515x.c, mfd_bq2515x.c]
2024-09-07 lp58xx: make reset more reliable, prevent spurious LSD faults
    The datasheet recommends setting the LSD threshold to 0.65 VCC.
    [lp58xx.c]
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2024-09-07 bq2515x: check CE pin value to determine status
2024-09-09 Only write WAV length at end.
    This avoids seeking which becomes progressively slower as the file gets
    larger. Also, adjust the buffering and thread priorities to try to
    reduce overruns.
2024-09-17 bq2515x: support LP pin
    LP must be high to communicate over I2C when VIN is not connected.
2024-09-21 audio: move frequency update to audio thread
    The sync work item was sometimes getting delayed and causing the block
    time queue to be empty. There's no real reason to use a workqueue for
    this; it can be done in the audio thread.
2024-09-25 Refactor wav library
    Improve file splitting and make sure we don't set the length to a
    partial sample if we run out of space.
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2024-10-04 audio: add power on/off support
    Add support for turning power on/off by long pressing the button. While
    the device is off, the LED shows the charging status.
2024-10-05 audio: fix charge LED when VIN is connected while powered on
    Update the charge LED state when a charging event is detected.
    [led.c, power.c]
2024-10-05 Add bq2515x_adc driver
    This allows reading the battery voltage, input voltage and input
    current.
2024-10-05 audio: add shell command for printing battery status
2024-10-05 Make led and power code common between audio and central
    Still needs some work to support unique LED patterns for central.
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2024-10-06 Use a different LED color for central node
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2024-10-11 Move battery shell command to common
    This requires a stupid hack to make the linker behave
    Also, flush the log before shutting down.
2024-10-11 power: enable VIN power good event
    This is used to update the charging state and was previously missing.
    [power.c]
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2024-10-20 Enable ADC power management.
    Put the ADC in sleep mode when not in use.
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2024-10-20 central: fix LED record status on startup
    [led.c, power.c]
2024-10-20 Synchronize LED pulses while recording
    Keep the periodic LED pulses while recording in sync on all devices.
2024-10-21 central: avoid triggering recording on startup
    Don't trigger a recording until the button has been released after
    startup.
    [main.c]
2024-10-21 central: integrte with common shell commands
    Define central shell commands so the "zeus battery" command from the
    common library works as well.
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2024-11-03 audio: allow custom file prefix
    Also, allow booting with no SD card inserted.
2024-11-06 audio: increase audio thread stack size
    There was a stack overflow when splitting files.
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2024-11-10 Fix simulator build
    Use GPIO and I2C emulators get drivers to build. The emulators aren't
    implemented yet but this is enough to get the firmware to boot.
    [main.c, power.c]
2024-11-23 Print file prefix as part of "zeus status"
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2024-12-10 pcb: add pull-downs for WiFi power
    [mcu.kicad_sch, power.kicad_sch, zeus-le.kicad_pcb]
2024-12-11 pcb: apply changes from manufacturing
    * Increase WLCSP stencil clearance to -10%
    * Use SMD WLCSP pads, dimensions from JLCPCB gerbers
    * Copper margin around NPTH, only those in my library so far
    [zeus-le.kicad_pcb]
2024-12-12 pcb: move rev-1 design to subdirectory
    The rev-2 design is not going to totally supersede the rev-1 design
    because they are different form factors. Therefore, keep rev-1 around
    in a separate directory.
    [audio.kicad_sch, led.kicad_sch, mcu.kicad_sch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]
2025-01-02 pcb: first draft of rev-2 PCB
    [audio.kicad_sch, led.kicad_sch, mcu.kicad_sch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]
2025-01-26 pcb: full rev-2 layout
    Mostly finished layout for the rev-2 board
    [audio.kicad_sch, mcu.kicad_sch, psram.kicad_sch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]
2025-01-28 pcb: minor schematic cleanup
    [audio.kicad_sch, mcu.kicad_sch, power.kicad_sch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]
2025-02-15 pcb: update
    Mostly downsize several decoupling capacitors to save space
    [audio.kicad_sch, led.kicad_sch, mcu.kicad_sch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]
2025-03-10 Increase PSRAM size to 64Mbit
    [psram.kicad_sch, zeus-le-rev-2.kicad_pcb]
2025-03-13 audio: disable network stack to increase the buffer size a bit
    Disable network stack which is currently not used anyway in order to
    save a bit of memory and allow slightly bigger buffers.
2025-03-13 audio: record 16-bit samples
    This reduces the data rate and increases the available buffer time,
    which will hopefully help with buffer overruns.
2025-06-14 pcb: upgrade to KiCad 9.0
    [audio.kicad_sch, led.kicad_sch, mcu.kicad_sch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]
2025-11-02 pcb: rev-2: add missing 3D models, rev-1: update to KiCAD 9
    [mcu.kicad_sch, power.kicad_sch, zeus-le-rev-2.kicad_pcb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]
2026-05-25 Update PCBs
    * Update to KiCad 10
    * Update footprint for nRF53 module based on 1.01 datasheet with
    actually readable mechanical drawing
    * Add 3D model for production nRF53 module
    * Remove overlapping silkscreen on rev-1 with production nRF53 module
    [audio.kicad_sch, led.kicad_sch, mcu.kicad_sch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]
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
